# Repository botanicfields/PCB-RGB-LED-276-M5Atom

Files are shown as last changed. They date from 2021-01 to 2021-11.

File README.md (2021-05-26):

# PCB-RGB-LED-276-M5Atom
Circle clock using 276pcs of WS2812C-2020 and an M5Atom

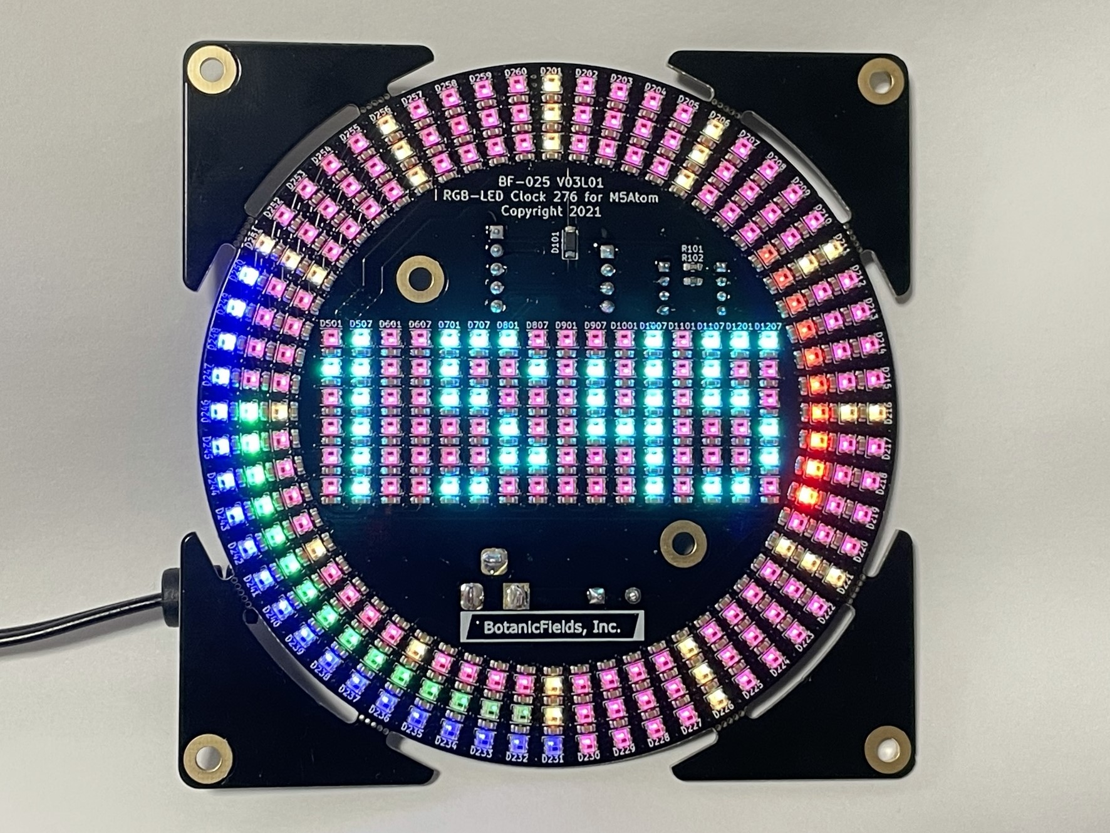
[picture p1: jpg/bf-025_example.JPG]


## 頒布

[M5Atom 用 RGB LED 276 基板](https://www.switch-science.com/catalog/7039/)

[M5Atom 用 RGB LED 276 基板（丸形）](https://botanicfields.booth.pm/items/2940057)

## 説明書

https://github.com/botanicfields/PCB-RGB-LED-276-M5Atom/blob/main/bf-025_doc.pdf

## RTC 基板の増設

　GROVE コネクタ経由でリアルタイムクロック (RTC) 基板を増設できます。スペーサを用いて 2 階建てにできます。

[M5 用 リアルタイムクロック (RTC) 基板](https://www.switch-science.com/catalog/7170/)

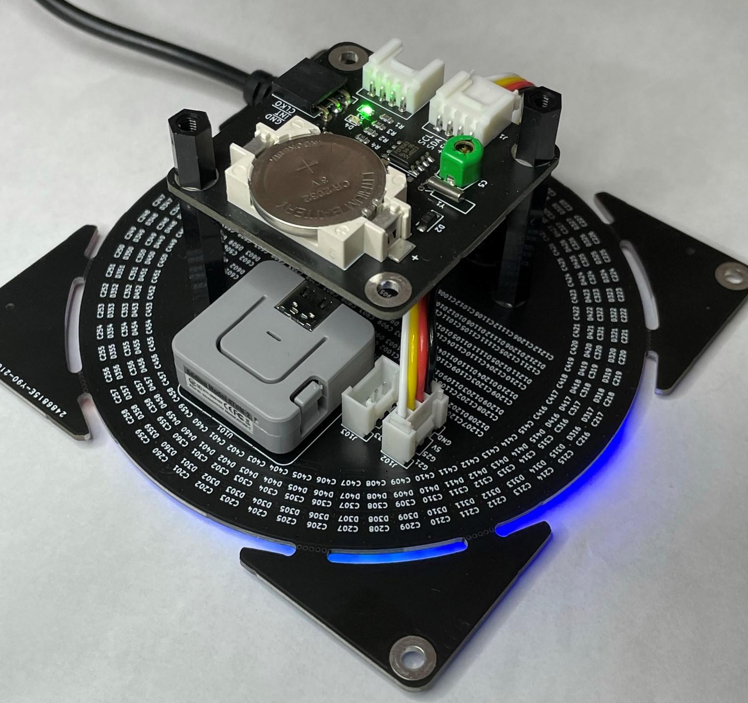
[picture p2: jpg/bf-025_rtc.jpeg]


## 置時計のデモ
　置時計のデモを作成しました。RTC に対応しました。RTC がなくても動作します。以下の機能があります。

- 時・分・秒・曜日・年・月・日の表示（スクロール）
- 時・分・秒のアナログ風表示（彗星の尾）
- 文字盤背景色の変化
- デモ: 時刻表示中のデモ (DemoClock)
- デモ: カウントダウンタイマー (DemoTimeShock)
- デモ: ランプテスト表示 (DemoCyron)
- デモ: 色相環表示 (DemoHueRing)
- デモ: パーリンノイズ (DemoNoise)

　時刻表示中のデモには以下があります。

- 文字色の切替（シアン・赤・緑・青）
- フォント表示（記号・数字、英大文字、英小文字）
- テキスト表示（英大文字、英小文字混在）
- エイリアン

　動作中 M5Atom のボタンで以下を操作します。切替の状況はシリアルモニタで確認できます。

|長押し時間|表示|効果|
|:-:|:-:|:-:|
| -  |Pale|カラーパレットを切替|
|>1 秒|Next|デモを切替、【クロックデモ】デモ内容を切替（文字色、フォント）|
|>2 秒|Exit|デモを切替|
|>3 秒|Temp|色温度を切替|
|>4 秒|Corr|色補正を切替|
|>5 秒|Scal|【パーリンノイズデモ】スケール (x, y) を切替|
|>6 秒|Peri|【パーリンノイズデモ】周期 (z) を切替|
|>7 秒|Null|ボタン操作を取消|

　カウントダウンタイマー動作中、M5Atom のボタンで以下を操作します。

|長押し時間|表示|状態|効果|
|:-:|:-:|:-:|:-:|
| - | - |カウントダウン停止中|カウントダウン開始|
| - | - |カウントダウン中|クイズモードに移行、賞金額を表示|
|>1 秒|Stop| - |カウントダウンを中止、初期値に戻す|
|>2 秒|Time| - |カウントダウンを中止、初期値を変更|
|>3 秒|Pale| - |カラーパレットを変更|
|>4 秒|Exit| - |終了、デモを切替|
|>5 秒|Null| - |ボタン操作を取消|

## 解説 Explanation
"Circle LED Clock by M5Atom and FastLED" in Japanese

[M5Atom と FastLED で 円形 LED 時計を作る](https://qiita.com/BotanicFields/items/a1e182f418d5a07120ac)

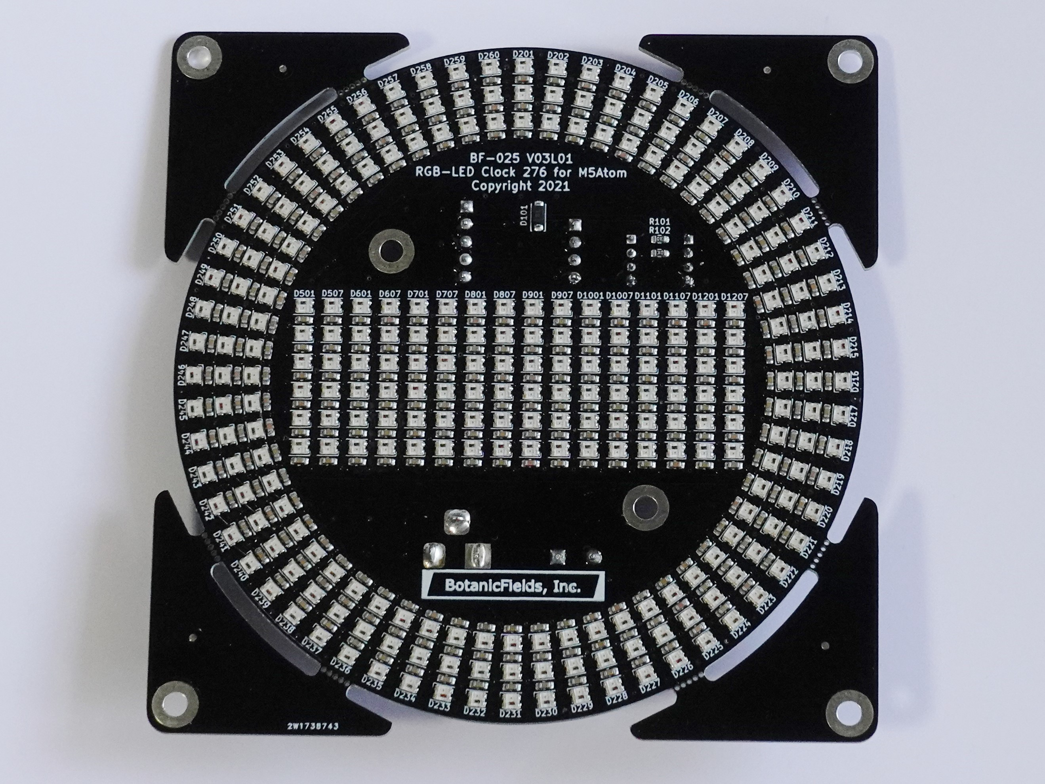
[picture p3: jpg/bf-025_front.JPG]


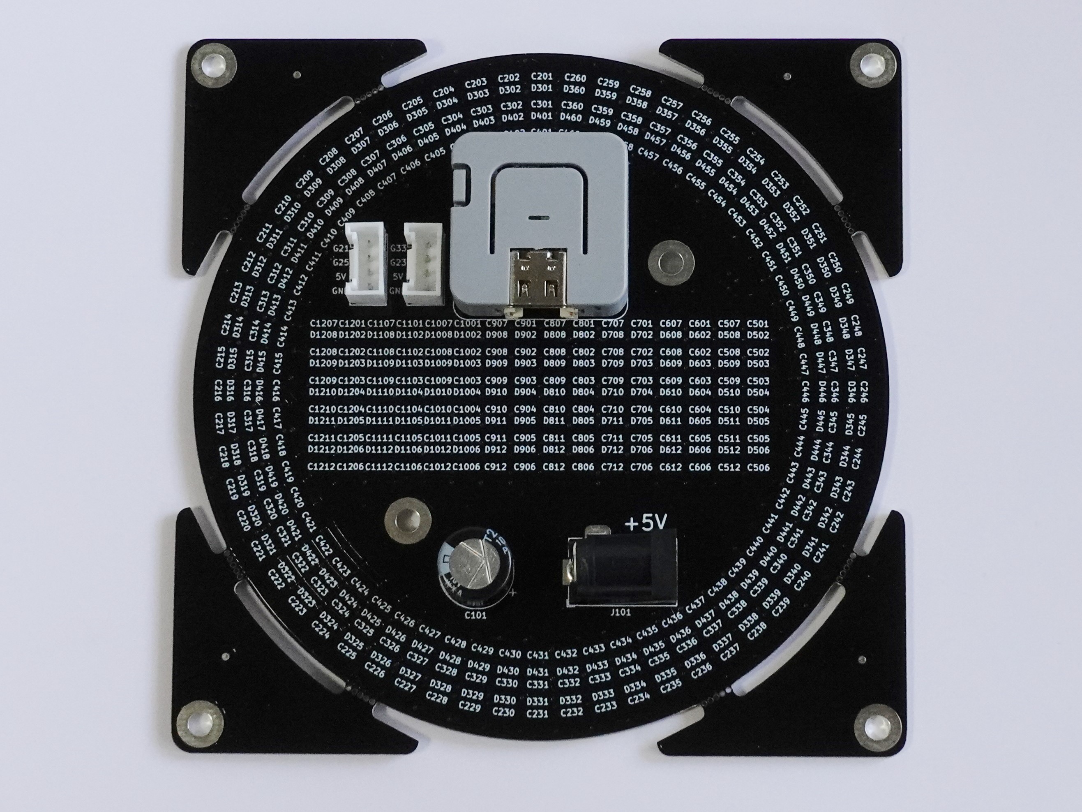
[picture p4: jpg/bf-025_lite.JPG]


## YouTube: Clock Demonstration 

[Clock Demo on BF-025: RGB-LED 276 for M5Atom](https://youtu.be/55dffut1Fk0)

## 3D images by KiCad:

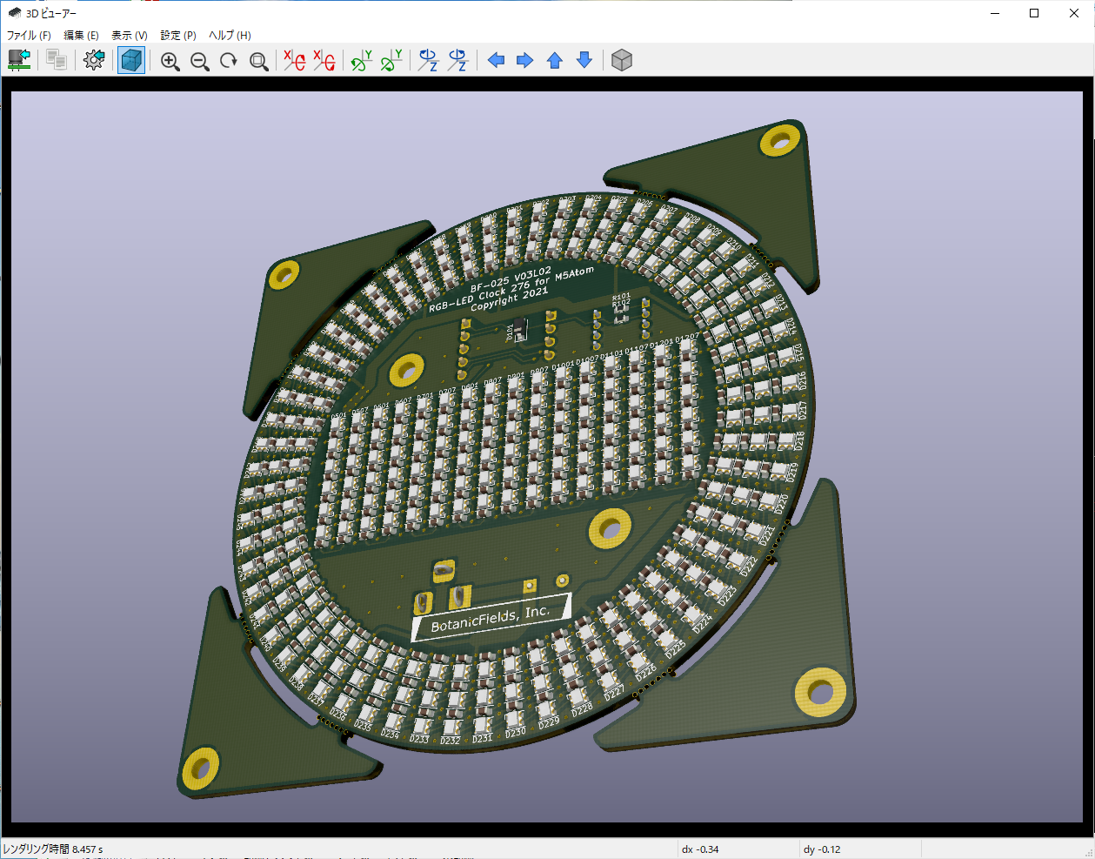
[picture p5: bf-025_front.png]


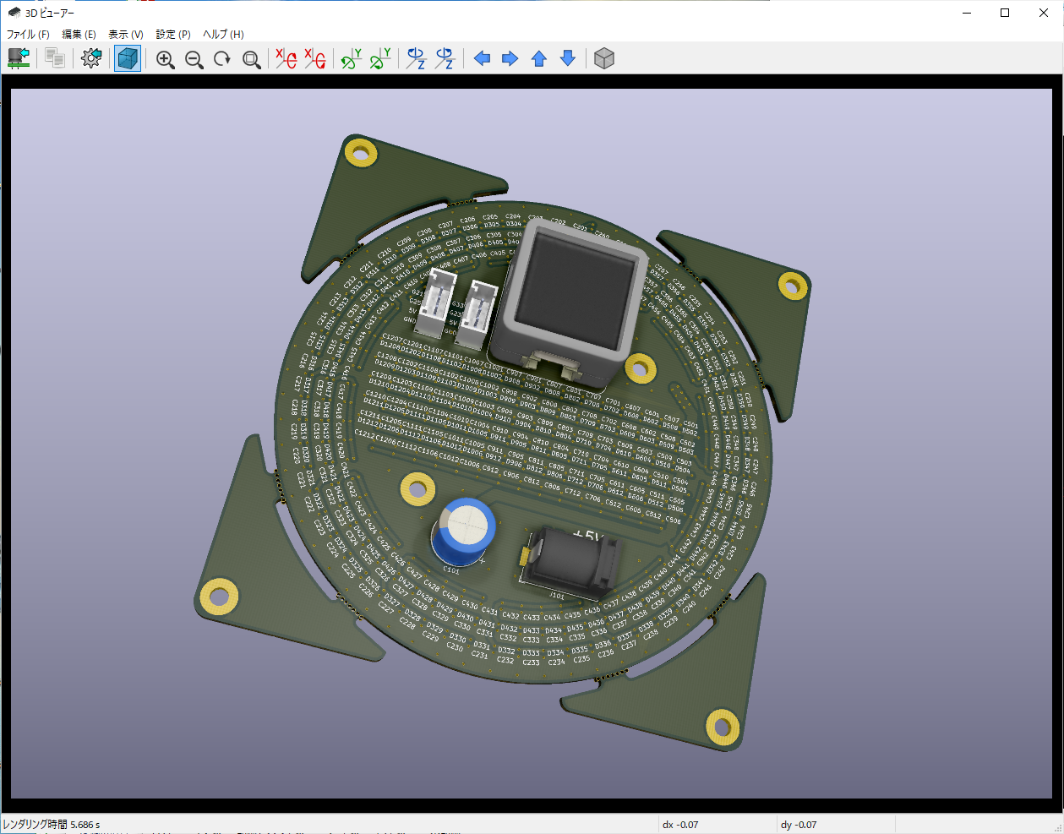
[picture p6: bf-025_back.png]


## YouTube: Examples

[ColorPalette an example from FastLED on BF-025: RGB-LED 276 for M5Atom](https://youtu.be/OUliTGfqcDM)

[DemoReel100 an example from FastLED on BF-025 RGB-LED 276 for M5Atom](https://youtu.be/VHuoHDQSU5E)

[Pacifica an example from FastLED on BF-025 RGB-LED 276 for M5Atom](https://youtu.be/MY5FGuDM8ZY)

[Pride2015 an example from FastLED on BF-025: RGB-LED 276 for M5Atom](https://youtu.be/uj7ePEQMkhk)

[TwinkleFox an exmaple from FastLED on BF025: RGB-LED 276 for M5Atom](https://youtu.be/3NwbCFiiEbc)

## Discussions

[JLCPCB official user group facebook](https://www.facebook.com/groups/JLCPCB/permalink/837468943770299/)

## Practical status of gerber, BOM, pick & place

### V02L01

- JLCPCB: OK

### V03L01

- ALLPCB: OK
- Seeed FusionPCB: OK

### V03L02

- ALLPCB: OK
- JLCPCB: OK

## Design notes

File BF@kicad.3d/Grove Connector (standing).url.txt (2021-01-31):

https://grabcad.com/library/grove-connectors-stand-and-flat-male-plugs-1

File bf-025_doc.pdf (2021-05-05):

BF-025 V03

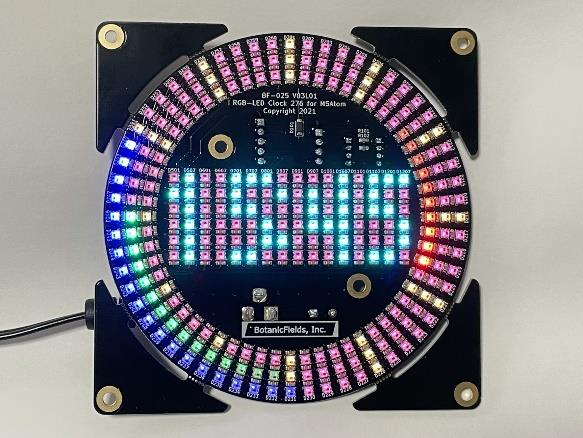
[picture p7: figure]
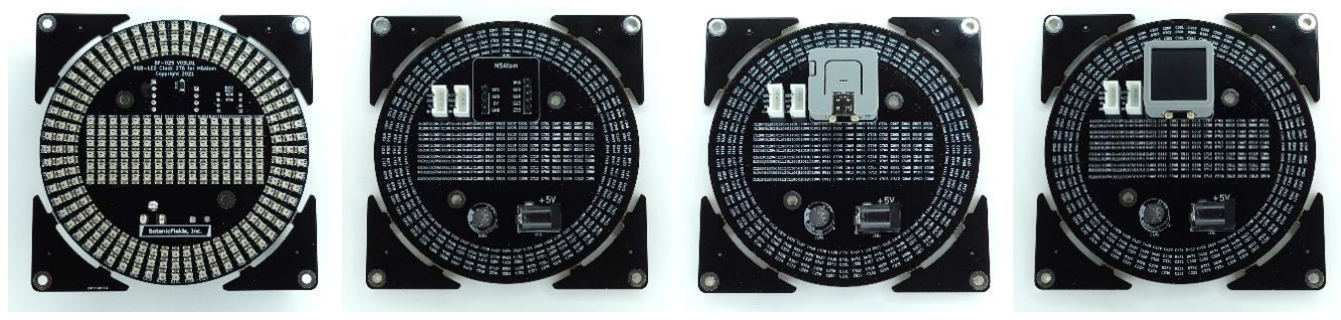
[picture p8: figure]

Copyright 2021 BotanicFields, Inc.

# M5Atom 用 RGB LED 276 基板

小型 RGB LED を、円形 60×3、長方形 16×6、計 276 個並べたプリント基板です。コントローラーに M5Atom Lite または M5Atom Matrix を使用してフルカラー表示 ができます。

※四隅がある基板と、最初から丸形の基板があります。

【安全上のご注意】
LED の明るさは、最大でも 1/4 に抑えてください。 FastLED の場合、明るさを 64 以下としてください。 FastLED.setBrightness(64);
1. 特徴
✓ | アナログ時計表示、デジタル時計表示に適した LED 配置
✓ | M5Atom 用のピンヘッダを装備し、配線の手間を削減
✓ | ポピュラーな NeoPixel 仕様のデジタル RGB LED（スマート LED）を使用
2. 内容物
✓ | プリント基板（完成品）
✓ | 説明書（本書）
※ M5Atom は付属しません。別途ご用意ください。
※ 電源は付属しません。5V 出力の AC アダプター等をご用意ください
| （例）秋月電子通商扱い
| 「スイッチングＡＣアダプター ５Ｖ２Ａ」
| https://akizukidenshi.com/catalog/g/gM-11996/

置時計デモ

表面 | 裏面 | M5Atom Lite 装着 | M5Atom Matrix 装着

3. 製品の特性
本製品は、電子工作や実験用の素材であり RGB LED のプログラミングを楽しんでいただくこと などを目的としています。置時計のデモプログラムには以下の様な制限があります。
✓ | 時刻合わせに Wi-Fi 接続、インターネット接続（NTP）が必須
| （※ Wi-Fi やインターネット接続が不安定だと、置時計自体が不安定になります。）
✓ | RTC やバッテリバックアップを内蔵しておらず、停電時の時刻保持機能がない
✓ | サウンド機能を内蔵しておらず、アラーム機能がない
✓ | 各種センサーを内蔵しておらず、明るさを自動制御する機能などがない
4. 必要なもの
(1) M5Atom
| プリント基板上のピンヘッダに M5Atom Lite または M5Atom Matrix を取り付けます。正し
| い取り付けを目視で確認してから、電源を接続するのが安全です。
| M5Atom Echo は使用できません。
(2) 電源
| DC ジャックから 5V 電源を供給します。M5Atom にも 5V を供給しており USB-C ケーブ
| ルを外しても動作を継続できます。M5Atom からの電源供給はできません。USB-C ケーブルを
| 接続すれば M5Atom 自体は動作します。RGB LED を光らせるためには DC ジャックからの
| 5V 電源の供給が必要です。
| LED の明るさは、最大でも 1/4 に抑えてください。これにより最大でも平均 1A（5W）の消
| 費電流（電力）に抑えることができます。プログラムを誤るなど、予想外の明るさになった場合は、
| 躊躇なく DC ジャックからプラグを抜いてください。
| 置時計のデモプログラムを実行中の消費電流（電力）は平均 0.2A 前後（1W 前後）、パーリン
| ノイズのデモを実行中は平均 0.35A 程度（2W 弱）です。
(3) プログラミング環境
| PC、USB-C ケーブル、ソフトウェアなど、M5Atoｍ にプログラムを書き込む設備環境が必要
| です。デモプログラムは、Arduino IDE を前提としています。コンパイル、書き込み、およびシ
| リアルモニタでの動作状況の確認ができます。Arduino IDE やデモプログラムの入手には一般に
| インターネット接続が必要です。
| Arduino IDE で M5Atom を使用するための準備は、以下の記事が参考になります。
| Qiita「M5Stack シリーズ製品を ArduinoIDE で使う」
| https://qiita.com/akita11/items/f896346d4e8be4673553
| M5Atom のライブラリは、GitHub から最新版を入手して置き換える方が良いと思います。
| さらに、ライブラリマネージャで、以下のライブラリをインストールしてください。
| ➢ FastLED by Daniel Garcia (3.4.0~) https://github.com/FastLED/FastLED
| ➢ WiFIManager by tzapu, tablatronix (2.0.3~) https://github.com/tzapu/WiFiManager

(4) Wi-Fi 接続
置時計のデモプログラムは、M5Atom を Wi-Fi 接続しインターネット上の NTP サーバから 時刻を得ています。
プログラムの書き込み、リセット、または電源オンで実行を開始すると、ランプテスト実行後に Wi-Fi 設定が動作します。Wi-Fi 設定は WiFiManager で行います。詳細は WiFiManager の説 明を参照ください。
https://github.com/tzapu/WiFiManager

大まかな流れ:
① 前回接続した SSID/Key で接続を試みる
② 接続できない場合、M5Atom 自身がアクセスポイントとなって、Wi-Fi クライアント からの接続を待つ
i. スマートフォン等で、アクセスポイントとなった M5Atom に接続する ※ SSID: ChipID に基づく名前、password/key: なし
ii. IP アドレス 192.168.4.1 でブラウザを開く
iii. M5Atom が接続すべき SSID/key を入力する
③ M5Atom が指定された SSID/key で Wi-Fi に接続する

Wi-Fi ルーターとの相性が悪かったり遠かったりすると、前回接続した SSID/Key での接続に 失敗することが多い模様です。この場合、Wi-Fi クライアントからの接続を待ち続けてしまいま す。この様子はシリアルモニタで確認できます。この場合、M5Atom のリセットボタンを押して 再起動すると接続できる場合があります。

(5) GROVE コネクタ
M5Atom の GPIO を GROVE コネクタ 2 個に取り出しています。M5Stack シリーズの仕様 に従い、電源は +5V です。
- | GPIO21※, GPIO25※, +5V, GND | ※3.3V プルアップ（10kΩ）あり
- GPIO33, GPIO23/GPIO34, +5V, GND
(6) パネル・ケースなど
LED 表示のコントラストを上げるには、スモークアクリル板によるパネルが有効です。また、 装飾には埃よけや取り付けのためのケースが必要です。これらの取り付けを想定して 3.2mm のネ ジ穴があります。四隅のネジ穴は、GND には繋がっていません。取り付けの際には、電気的なシ ョート防止および放熱への考慮が必要です。プリント基板の四隅を切り取る場合は、断線や部品破 損を防止するため細心の注意が必要です。
※四隅がある基板と、最初から丸形の基板があります。

5. 情報
回路図、実装図、部品ライブラリ、製造データ、デモプログラム、説明書は、以下にあります。 GitHub 「botanicfields/PCB-RGB-LED-276-M5Atom」 https://github.com/botanicfields/PCB-RGB-LED-276-M5Atom

ハードウェア構成やライブラリ（FastLED）の適用について以下の記事にまとめています。 Qiita 「M5Atom と FastLED で 円形 LED 時計を作る」 https://qiita.com/BotanicFields/items/a1e182f418d5a07120ac

この説明書の内容は古くなっている可能性があります。最新情報は、上記を参照ください。

6. 置時計
置時計のデモプログラムを作成しました。動作の様子が YouTube にあります。 YouTube 「Clock Demo on BF-025: RGB-LED 276 for M5Atom」 https://youtu.be/55dffut1Fk0

Arduino IDE において、名前 BF-025 のフォルダをまるごと置いてください。 GitHub 「PCB-RGB-LED-276-M5Atom/BF-025/」 https://github.com/botanicfields/PCB-RGB-LED-276-M5Atom/tree/main/BF-025

置時計デモプログラムには以下の機能があります。
✓ | 時・分・秒・曜日・年・月・日をスクロール表示
✓ | 時・分・秒をアナログ風に表示（彗星の尾）
✓ | 文字盤背景色が変化
✓ | デモ: 時刻表示中のデモ (DemoClock)
✓ | デモ: カウントダウンタイマー (DemoTimeShock)
✓ | デモ: ランプテスト表示 (DemoCyron)
✓ | デモ: 色相環表示 (DemoHueRing)
✓ | デモ: パーリンノイズ (DemoNoise)

時刻表示中のデモには以下があります。
✓ | 文字色を切替（シアン・赤・緑・青）
✓ | フォント一覧を表示（記号・数字、英大文字、英小文字）
✓ | テキスト（サンプル）を表示（英大文字、英小文字混在）
✓ | エイリアンを表示

動作中 M5Atom のボタンで、色やデモを切り替えることができます。ボタン操作には長押しを利 用しています。切替の状況はシリアルモニタで確認できます。

長押し時間 | 表示 | 効果
- | Pale | カラーパレットを切替
>1 秒 | Next | デモを切替、【クロックデモ】デモ内容を切替（文字色、フォント）
>2 秒 | Exit | デモを切替
>3 秒 | Temp | 色温度を切替
>4 秒 | Corr | 色補正を切替
>5 秒 | Scal | 【パーリンノイズデモ】スケール (x, y) を切替
>6 秒 | Peri | 【パーリンノイズデモ】周期 (z) を切替
>7 秒 | Null | ボタン操作を取消

カウントダウンタイマーのデモ動作中、M5Atom のボタン操作は以下のとおりです。
長押し時間 | 表示 | 状態 | 効果
- | - | カウントダウン停止中 | カウントダウン開始
- | - | カウントダウン中 | クイズモードに移行、賞金額（千円）を表示
>1 秒 | Stop | - | カウントダウンを中止、初期値に戻す
>2 秒 | Time | - | カウントダウンを中止、初期値を変更
>3 秒 | Pale | - | カラーパレットを変更
>4 秒 | Exit | - | 終了、デモを切替
>5 秒 | Null | - | ボタン操作を取消
7. 修理について
頒布にあたり正常動作を確認しておりますが、使用中に不具合が発生する可能性はゼロではあり ません。万一不具合が発生した場合は、ご自身で修理なさるか、または提供元にご相談ください。
8. 提供元
ボタニック BotanicFields, Inc.
https://www.facebook.com/botanicfieldshttps://twitter.com/botanicfields
以上

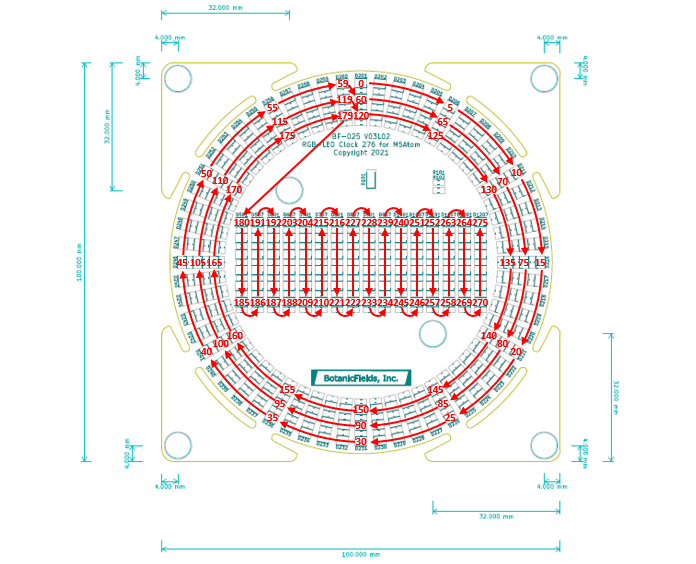
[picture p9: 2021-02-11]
bf-025_led_connection.png

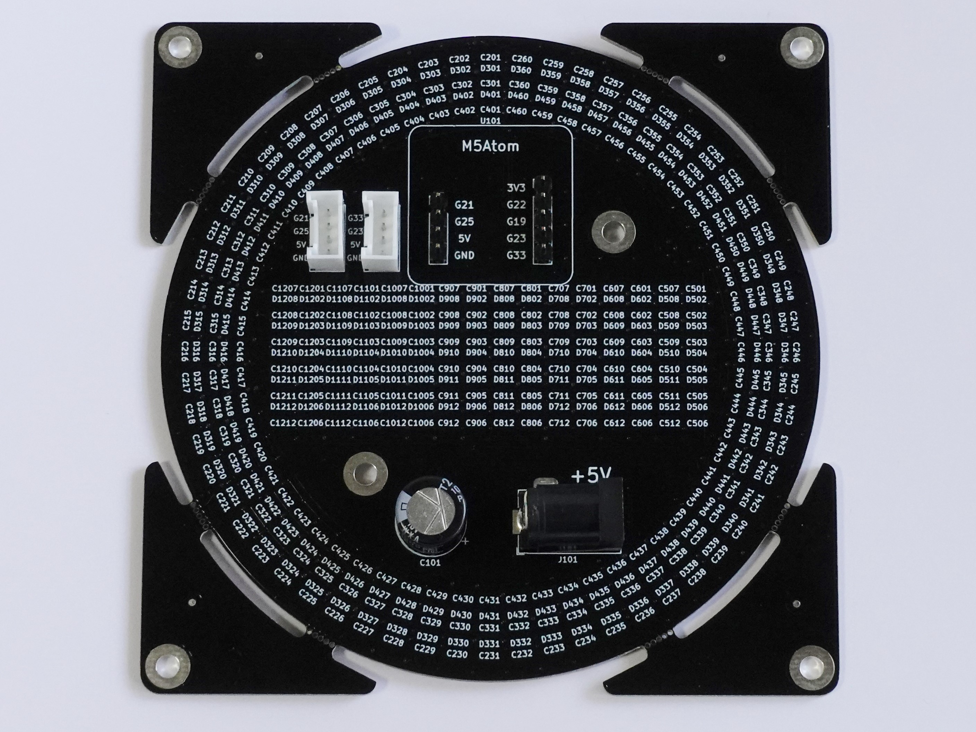
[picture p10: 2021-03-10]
jpg/bf-025_back.JPG

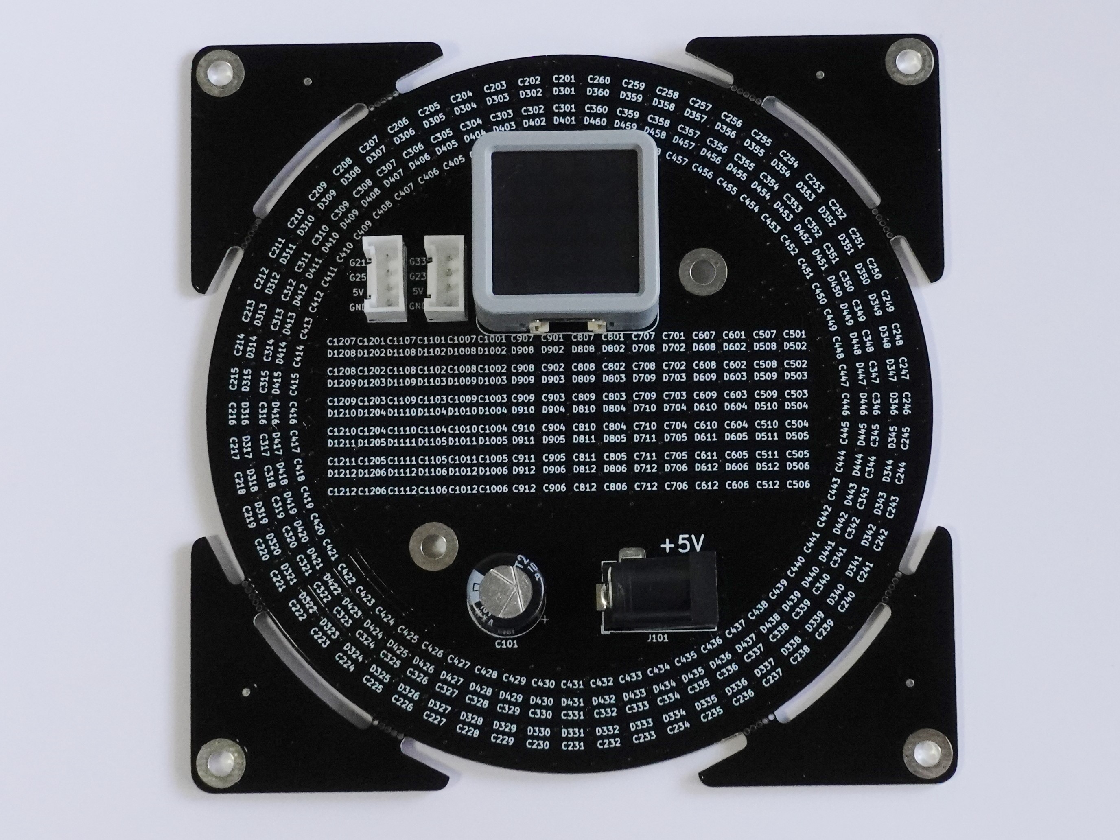
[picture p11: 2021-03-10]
jpg/bf-025_matrix.JPG

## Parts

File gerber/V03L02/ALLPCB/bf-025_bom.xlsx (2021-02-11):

Qty | MPN | Supplier | Reference | Value | Package | Type | Notes | Link
276 | CC0603KRX7R9BB104 | LCSC | C201,C202,C203,C204,C205,C206,C207,C208,C209,C210,C211,C212,C213,C214,C215,C216,C217,C218,C219,C220,C221,C222,C223,C224,C225,C226,C227,C228,C229,C230,C231,C232,C233,C234,C235,C236,C237,C238,C239,C240,C241,C242,C243,C244,C245,C246,C247,C248,C249,C250,C251,C252,C253,C254,C255,C256,C257,C258,C259,C260,C301,C302,C303,C304,C305,C306,C307,C308,C309,C310,C311,C312,C313,C314,C315,C316,C317,C318,C319,C320,C321,C322,C323,C324,C325,C326,C327,C328,C329,C330,C331,C332,C333,C334,C335,C336,C337,C338,C339,C340,C341,C342,C343,C344,C345,C346,C347,C348,C349,C350,C351,C352,C353,C354,C355,C356,C357,C358,C359,C360,C401,C402,C403,C404,C405,C406,C407,C408,C409,C410,C411,C412,C413,C414,C415,C416,C417,C418,C419,C420,C421,C422,C423,C424,C425,C426,C427,C428,C429,C430,C431,C432,C433,C434,C435,C436,C437,C438,C439,C440,C441,C442,C443,C444,C445,C446,C447,C448,C449,C450,C451,C452,C453,C454,C455,C456,C457,C458,C459,C460,C501,C502,C503,C504,C505,C506,C507,C508,C509,C510,C511,C512,C601,C602,C603,C604,C605,C606,C607,C608,C609,C610,C611,C612,C701,C702,C703,C704,C705,C706,C707,C708,C709,C710,C711,C712,C801,C802,C803,C804,C805,C806,C807,C808,C809,C810,C811,C812,C901,C902,C903,C904,C905,C906,C907,C908,C909,C910,C911,C912,C1001,C1002,C1003,C1004,C1005,C1006,C1007,C1008,C1009,C1010,C1011,C1012,C1101,C1102,C1103,C1104,C1105,C1106,C1107,C1108,C1109,C1110,C1111,C1112,C1201,C1202,C1203,C1204,C1205,C1206,C1207,C1208,C1209,C1210,C1211,C1212 | 100n | C0603 | SMD | LCSC: C14663 Substitutable
1 | B5819W | LCSC | D101 | B5819W | SOD-123 | SMD | LCSC: C8598
276 | WS2812C-2020 | LCSC | D201,D202,D203,D204,D205,D206,D207,D208,D209,D210,D211,D212,D213,D214,D215,D216,D217,D218,D219,D220,D221,D222,D223,D224,D225,D226,D227,D228,D229,D230,D231,D232,D233,D234,D235,D236,D237,D238,D239,D240,D241,D242,D243,D244,D245,D246,D247,D248,D249,D250,D251,D252,D253,D254,D255,D256,D257,D258,D259,D260,D301,D302,D303,D304,D305,D306,D307,D308,D309,D310,D311,D312,D313,D314,D315,D316,D317,D318,D319,D320,D321,D322,D323,D324,D325,D326,D327,D328,D329,D330,D331,D332,D333,D334,D335,D336,D337,D338,D339,D340,D341,D342,D343,D344,D345,D346,D347,D348,D349,D350,D351,D352,D353,D354,D355,D356,D357,D358,D359,D360,D401,D402,D403,D404,D405,D406,D407,D408,D409,D410,D411,D412,D413,D414,D415,D416,D417,D418,D419,D420,D421,D422,D423,D424,D425,D426,D427,D428,D429,D430,D431,D432,D433,D434,D435,D436,D437,D438,D439,D440,D441,D442,D443,D444,D445,D446,D447,D448,D449,D450,D451,D452,D453,D454,D455,D456,D457,D458,D459,D460,D501,D502,D503,D504,D505,D506,D507,D508,D509,D510,D511,D512,D601,D602,D603,D604,D605,D606,D607,D608,D609,D610,D611,D612,D701,D702,D703,D704,D705,D706,D707,D708,D709,D710,D711,D712,D801,D802,D803,D804,D805,D806,D807,D808,D809,D810,D811,D812,D901,D902,D903,D904,D905,D906,D907,D908,D909,D910,D911,D912,D1001,D1002,D1003,D1004,D1005,D1006,D1007,D1008,D1009,D1010,D1011,D1012,D1101,D1102,D1103,D1104,D1105,D1106,D1107,D1108,D1109,D1110,D1111,D1112,D1201,D1202,D1203,D1204,D1205,D1206,D1207,D1208,D1209,D1210,D1211,D1212 | WS2812C-2020 | D2020 | SMD | LCSC: C965556 | http://www.world-semi.com/Certifications/details-139-4.html
2 | 0603WAF1002T5E | LCSC | R101,R102 | 10kOhm | R0603 | SMD | LCSC: C25804 Substitutable

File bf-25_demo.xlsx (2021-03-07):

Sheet: Font Editor
 | Font Editor 6*6
 |  |  |  |  | ↓フォントを編集します |  |  |  |  |  |  |  |  | フィルターで空白行を非表示にし、コピーしてください↓
 | code | hex | character |  | Editing area |  |  |  |  |  |  |  |  | x*y = 6*6 fonts data
1 |  |  |  |  | 0 | 1 | 2 | 3 | 4 | 5 | 6 | 7
2 |  |  |  |  | 128 | 64 | 32 | 16 | 8 | 4 | 2 | 1
3 | 0 | 0x00 | 0 |  |  |  |  |  |  |  |  |  |  | { 0x60, 0xA0, 0xA0, 0xA0, 0xA0, 0xC0, }, // 0x00 0
4 |  |  |  | 1 |  | 1 | 1 |  |  |  |  |  | 0x60,
5 |  |  |  | 2 | 1 |  | 1 |  |  |  |  |  | 0xA0,
6 |  |  |  | 3 | 1 |  | 1 |  |  |  |  |  | 0xA0,
7 |  |  |  | 4 | 1 |  | 1 |  |  |  |  |  | 0xA0,
8 |  |  |  | 5 | 1 |  | 1 |  |  |  |  |  | 0xA0,
9 |  |  |  | 6 | 1 | 1 |  |  |  |  |  |  | 0xC0,
10 | 1 | 0x01 | 1 |  |  |  |  |  |  |  |  |  |  | { 0x40, 0xC0, 0x40, 0x40, 0x40, 0x40, }, // 0x01 1
11 |  |  |  | 1 |  | 1 |  |  |  |  |  |  | 0x40,
12 |  |  |  | 2 | 1 | 1 |  |  |  |  |  |  | 0xC0,
13 |  |  |  | 3 |  | 1 |  |  |  |  |  |  | 0x40,
14 |  |  |  | 4 |  | 1 |  |  |  |  |  |  | 0x40,
15 |  |  |  | 5 |  | 1 |  |  |  |  |  |  | 0x40,
16 |  |  |  | 6 |  | 1 |  |  |  |  |  |  | 0x40,
17 | 2 | 0x02 | 2 |  |  |  |  |  |  |  |  |  |  | { 0xC0, 0x20, 0x20, 0x40, 0x80, 0xE0, }, // 0x02 2
18 |  |  |  | 1 | 1 | 1 |  |  |  |  |  |  | 0xC0,
19 |  |  |  | 2 |  |  | 1 |  |  |  |  |  | 0x20,
20 |  |  |  | 3 |  |  | 1 |  |  |  |  |  | 0x20,
21 |  |  |  | 4 |  | 1 |  |  |  |  |  |  | 0x40,
22 |  |  |  | 5 | 1 |  |  |  |  |  |  |  | 0x80,
23 |  |  |  | 6 | 1 | 1 | 1 |  |  |  |  |  | 0xE0,
24 | 3 | 0x03 | 3 |  |  |  |  |  |  |  |  |  |  | { 0xC0, 0x20, 0x40, 0x20, 0x20, 0xC0, }, // 0x03 3
25 |  |  |  | 1 | 1 | 1 |  |  |  |  |  |  | 0xC0,
26 |  |  |  | 2 |  |  | 1 |  |  |  |  |  | 0x20,
27 |  |  |  | 3 |  | 1 |  |  |  |  |  |  | 0x40,
28 |  |  |  | 4 |  |  | 1 |  |  |  |  |  | 0x20,
29 |  |  |  | 5 |  |  | 1 |  |  |  |  |  | 0x20,
30 |  |  |  | 6 | 1 | 1 |  |  |  |  |  |  | 0xC0,
31 | 4 | 0x04 | 4 |  |  |  |  |  |  |  |  |  |  | { 0x20, 0xA0, 0xA0, 0xE0, 0x20, 0x20, }, // 0x04 4
32 |  |  |  | 1 |  |  | 1 |  |  |  |  |  | 0x20,
33 |  |  |  | 2 | 1 |  | 1 |  |  |  |  |  | 0xA0,
34 |  |  |  | 3 | 1 |  | 1 |  |  |  |  |  | 0xA0,
35 |  |  |  | 4 | 1 | 1 | 1 |  |  |  |  |  | 0xE0,
36 |  |  |  | 5 |  |  | 1 |  |  |  |  |  | 0x20,
37 |  |  |  | 6 |  |  | 1 |  |  |  |  |  | 0x20,
38 | 5 | 0x05 | 5 |  |  |  |  |  |  |  |  |  |  | { 0xE0, 0x80, 0xC0, 0x20, 0x20, 0xC0, }, // 0x05 5
39 |  |  |  | 1 | 1 | 1 | 1 |  |  |  |  |  | 0xE0,
40 |  |  |  | 2 | 1 |  |  |  |  |  |  |  | 0x80,
41 |  |  |  | 3 | 1 | 1 |  |  |  |  |  |  | 0xC0,
42 |  |  |  | 4 |  |  | 1 |  |  |  |  |  | 0x20,
43 |  |  |  | 5 |  |  | 1 |  |  |  |  |  | 0x20,
44 |  |  |  | 6 | 1 | 1 |  |  |  |  |  |  | 0xC0,
45 | 6 | 0x06 | 6 |  |  |  |  |  |  |  |  |  |  | { 0x60, 0x80, 0xC0, 0xA0, 0xA0, 0x40, }, // 0x06 6
46 |  |  |  | 1 |  | 1 | 1 |  |  |  |  |  | 0x60,
47 |  |  |  | 2 | 1 |  |  |  |  |  |  |  | 0x80,
48 |  |  |  | 3 | 1 | 1 |  |  |  |  |  |  | 0xC0,
49 |  |  |  | 4 | 1 |  | 1 |  |  |  |  |  | 0xA0,
50 |  |  |  | 5 | 1 |  | 1 |  |  |  |  |  | 0xA0,
51 |  |  |  | 6 |  | 1 |  |  |  |  |  |  | 0x40,
52 | 7 | 0x07 | 7 |  |  |  |  |  |  |  |  |  |  | { 0xE0, 0x20, 0x20, 0x40, 0x80, 0x80, }, // 0x07 7
53 |  |  |  | 1 | 1 | 1 | 1 |  |  |  |  |  | 0xE0,
54 |  |  |  | 2 |  |  | 1 |  |  |  |  |  | 0x20,
55 |  |  |  | 3 |  |  | 1 |  |  |  |  |  | 0x20,
56 |  |  |  | 4 |  | 1 |  |  |  |  |  |  | 0x40,
57 |  |  |  | 5 | 1 |  |  |  |  |  |  |  | 0x80,
58 |  |  |  | 6 | 1 |  |  |  |  |  |  |  | 0x80,
59 | 8 | 0x08 | 8 |  |  |  |  |  |  |  |  |  |  | { 0x60, 0xA0, 0x40, 0xA0, 0xA0, 0xC0, }, // 0x08 8
60 |  |  |  | 1 |  | 1 | 1 |  |  |  |  |  | 0x60,
61 |  |  |  | 2 | 1 |  | 1 |  |  |  |  |  | 0xA0,
62 |  |  |  | 3 |  | 1 |  |  |  |  |  |  | 0x40,
63 |  |  |  | 4 | 1 |  | 1 |  |  |  |  |  | 0xA0,
64 |  |  |  | 5 | 1 |  | 1 |  |  |  |  |  | 0xA0,
65 |  |  |  | 6 | 1 | 1 |  |  |  |  |  |  | 0xC0,
66 | 9 | 0x09 | 9 |  |  |  |  |  |  |  |  |  |  | { 0x40, 0xA0, 0xA0, 0x60, 0x20, 0xC0, }, // 0x09 9
67 |  |  |  | 1 |  | 1 |  |  |  |  |  |  | 0x40,
68 |  |  |  | 2 | 1 |  | 1 |  |  |  |  |  | 0xA0,
69 |  |  |  | 3 | 1 |  | 1 |  |  |  |  |  | 0xA0,
70 |  |  |  | 4 |  | 1 | 1 |  |  |  |  |  | 0x60,
71 |  |  |  | 5 |  |  | 1 |  |  |  |  |  | 0x20,
72 |  |  |  | 6 | 1 | 1 |  |  |  |  |  |  | 0xC0,
73 | 10 | 0x0A | A |  |  |  |  |  |  |  |  |  |  | { 0x40, 0xA0, 0xA0, 0xE0, 0xA0, 0xA0, }, // 0x0A A
74 |  |  |  | 1 |  | 1 |  |  |  |  |  |  | 0x40,
75 |  |  |  | 2 | 1 |  | 1 |  |  |  |  |  | 0xA0,
76 |  |  |  | 3 | 1 |  | 1 |  |  |  |  |  | 0xA0,
77 |  |  |  | 4 | 1 | 1 | 1 |  |  |  |  |  | 0xE0,
78 |  |  |  | 5 | 1 |  | 1 |  |  |  |  |  | 0xA0,
79 |  |  |  | 6 | 1 |  | 1 |  |  |  |  |  | 0xA0,
80 | 11 | 0x0B | B |  |  |  |  |  |  |  |  |  |  | { 0xC0, 0xA0, 0xC0, 0xA0, 0xA0, 0xC0, }, // 0x0B B
81 |  |  |  | 1 | 1 | 1 |  |  |  |  |  |  | 0xC0,
82 |  |  |  | 2 | 1 |  | 1 |  |  |  |  |  | 0xA0,
83 |  |  |  | 3 | 1 | 1 |  |  |  |  |  |  | 0xC0,
84 |  |  |  | 4 | 1 |  | 1 |  |  |  |  |  | 0xA0,
85 |  |  |  | 5 | 1 |  | 1 |  |  |  |  |  | 0xA0,
86 |  |  |  | 6 | 1 | 1 |  |  |  |  |  |  | 0xC0,
87 | 12 | 0x0C | C |  |  |  |  |  |  |  |  |  |  | { 0x60, 0x80, 0x80, 0x80, 0x80, 0x60, }, // 0x0C C
88 |  |  |  | 1 |  | 1 | 1 |  |  |  |  |  | 0x60,
89 |  |  |  | 2 | 1 |  |  |  |  |  |  |  | 0x80,
90 |  |  |  | 3 | 1 |  |  |  |  |  |  |  | 0x80,
91 |  |  |  | 4 | 1 |  |  |  |  |  |  |  | 0x80,
92 |  |  |  | 5 | 1 |  |  |  |  |  |  |  | 0x80,
93 |  |  |  | 6 |  | 1 | 1 |  |  |  |  |  | 0x60,
94 | 13 | 0x0D | D |  |  |  |  |  |  |  |  |  |  | { 0xC0, 0xA0, 0xA0, 0xA0, 0xA0, 0xC0, }, // 0x0D D
95 |  |  |  | 1 | 1 | 1 |  |  |  |  |  |  | 0xC0,
96 |  |  |  | 2 | 1 |  | 1 |  |  |  |  |  | 0xA0,
97 |  |  |  | 3 | 1 |  | 1 |  |  |  |  |  | 0xA0,
98 |  |  |  | 4 | 1 |  | 1 |  |  |  |  |  | 0xA0,
99 |  |  |  | 5 | 1 |  | 1 |  |  |  |  |  | 0xA0,
100 |  |  |  | 6 | 1 | 1 |  |  |  |  |  |  | 0xC0,
101 | 14 | 0x0E | E |  |  |  |  |  |  |  |  |  |  | { 0xE0, 0x80, 0xE0, 0x80, 0x80, 0xE0, }, // 0x0E E
102 |  |  |  | 1 | 1 | 1 | 1 |  |  |  |  |  | 0xE0,
103 |  |  |  | 2 | 1 |  |  |  |  |  |  |  | 0x80,
104 |  |  |  | 3 | 1 | 1 | 1 |  |  |  |  |  | 0xE0,
105 |  |  |  | 4 | 1 |  |  |  |  |  |  |  | 0x80,
106 |  |  |  | 5 | 1 |  |  |  |  |  |  |  | 0x80,
107 |  |  |  | 6 | 1 | 1 | 1 |  |  |  |  |  | 0xE0,
108 | 15 | 0x0F | F |  |  |  |  |  |  |  |  |  |  | { 0xE0, 0x80, 0xE0, 0x80, 0x80, 0x80, }, // 0x0F F
109 |  |  |  | 1 | 1 | 1 | 1 |  |  |  |  |  | 0xE0,
110 |  |  |  | 2 | 1 |  |  |  |  |  |  |  | 0x80,
111 |  |  |  | 3 | 1 | 1 | 1 |  |  |  |  |  | 0xE0,
112 |  |  |  | 4 | 1 |  |  |  |  |  |  |  | 0x80,
113 |  |  |  | 5 | 1 |  |  |  |  |  |  |  | 0x80,
114 |  |  |  | 6 | 1 |  |  |  |  |  |  |  | 0x80,
115 | 16 | 0x10 | Crab1L |  |  |  |  |  |  |  |  |  |  | { 0x60, 0x3C, 0x6C, 0xFC, 0x90, 0x18, }, // 0x10 Crab1L
116 |  |  |  | 1 |  | 1 | 1 |  |  |  |  |  | 0x60,
117 |  |  |  | 2 |  |  | 1 | 1 | 1 | 1 |  |  | 0x3C,
118 |  |  |  | 3 |  | 1 | 1 |  | 1 | 1 |  |  | 0x6C,
119 |  |  |  | 4 | 1 | 1 | 1 | 1 | 1 | 1 |  |  | 0xFC,
120 |  |  |  | 5 | 1 |  |  | 1 |  |  |  |  | 0x90,
121 |  |  |  | 6 |  |  |  | 1 | 1 |  |  |  | 0x18,
122 | 17 | 0x11 | Crab1R |  |  |  |  |  |  |  |  |  |  | { 0x30, 0xE0, 0xB0, 0xF8, 0x48, 0xC0, }, // 0x11 Crab1R
123 |  |  |  | 1 |  |  | 1 | 1 |  |  |  |  | 0x30,
124 |  |  |  | 2 | 1 | 1 | 1 |  |  |  |  |  | 0xE0,
125 |  |  |  | 3 | 1 |  | 1 | 1 |  |  |  |  | 0xB0,
126 |  |  |  | 4 | 1 | 1 | 1 | 1 | 1 |  |  |  | 0xF8,
127 |  |  |  | 5 |  | 1 |  |  | 1 |  |  |  | 0x48,
128 |  |  |  | 6 | 1 | 1 |  |  |  |  |  |  | 0xC0,
129 | 18 | 0x12 | Crab2L |  |  |  |  |  |  |  |  |  |  | { 0x20, 0xBC, 0xEC, 0x7C, 0x10, 0x30, }, // 0x12 Crab2L
130 |  |  |  | 1 |  |  | 1 |  |  |  |  |  | 0x20,
131 |  |  |  | 2 | 1 |  | 1 | 1 | 1 | 1 |  |  | 0xBC,
132 |  |  |  | 3 | 1 | 1 | 1 |  | 1 | 1 |  |  | 0xEC,
133 |  |  |  | 4 |  | 1 | 1 | 1 | 1 | 1 |  |  | 0x7C,
134 |  |  |  | 5 |  |  |  | 1 |  |  |  |  | 0x10,
135 |  |  |  | 6 |  |  | 1 | 1 |  |  |  |  | 0x30,
136 | 19 | 0x13 | Crab2R |  |  |  |  |  |  |  |  |  |  | { 0x20, 0xE8, 0xB8, 0xF0, 0x40, 0x60, }, // 0x13 Crab2R
137 |  |  |  | 1 |  |  | 1 |  |  |  |  |  | 0x20,
138 |  |  |  | 2 | 1 | 1 | 1 |  | 1 |  |  |  | 0xE8,
139 |  |  |  | 3 | 1 |  | 1 | 1 | 1 |  |  |  | 0xB8,
140 |  |  |  | 4 | 1 | 1 | 1 | 1 |  |  |  |  | 0xF0,
141 |  |  |  | 5 |  | 1 |  |  |  |  |  |  | 0x40,
142 |  |  |  | 6 |  | 1 | 1 |  |  |  |  |  | 0x60,
143 | 20 | 0x14 | Octopus1L |  |  |  |  |  |  |  |  |  |  | { 0x3C, 0x7C, 0x6C, 0x7C, 0x24, 0xC8, }, // 0x14 Octopus1L
144 |  |  |  | 1 |  |  | 1 | 1 | 1 | 1 |  |  | 0x3C,
145 |  |  |  | 2 |  | 1 | 1 | 1 | 1 | 1 |  |  | 0x7C,
146 |  |  |  | 3 |  | 1 | 1 |  | 1 | 1 |  |  | 0x6C,
147 |  |  |  | 4 |  | 1 | 1 | 1 | 1 | 1 |  |  | 0x7C,
148 |  |  |  | 5 |  |  | 1 |  |  | 1 |  |  | 0x24,
149 |  |  |  | 6 | 1 | 1 |  |  | 1 |  |  |  | 0xC8,
150 | 21 | 0x15 | Octopus1R |  |  |  |  |  |  |  |  |  |  | { 0xE0, 0xF0, 0xB0, 0xF0, 0x20, 0x98, }, // 0x15 Octopus1R
151 |  |  |  | 1 | 1 | 1 | 1 |  |  |  |  |  | 0xE0,
152 |  |  |  | 2 | 1 | 1 | 1 | 1 |  |  |  |  | 0xF0,
153 |  |  |  | 3 | 1 |  | 1 | 1 |  |  |  |  | 0xB0,
154 |  |  |  | 4 | 1 | 1 | 1 | 1 |  |  |  |  | 0xF0,
155 |  |  |  | 5 |  |  | 1 |  |  |  |  |  | 0x20,
156 |  |  |  | 6 | 1 |  |  | 1 | 1 |  |  |  | 0x98,
157 | 22 | 0x16 | Octopus2L |  |  |  |  |  |  |  |  |  |  | { 0x3C, 0x7C, 0x6C, 0x7C, 0x24, 0x14, }, // 0x16 Octopus2L
158 |  |  |  | 1 |  |  | 1 | 1 | 1 | 1 |  |  | 0x3C,
159 |  |  |  | 2 |  | 1 | 1 | 1 | 1 | 1 |  |  | 0x7C,
160 |  |  |  | 3 |  | 1 | 1 |  | 1 | 1 |  |  | 0x6C,
161 |  |  |  | 4 |  | 1 | 1 | 1 | 1 | 1 |  |  | 0x7C,
162 |  |  |  | 5 |  |  | 1 |  |  | 1 |  |  | 0x24,
163 |  |  |  | 6 |  |  |  | 1 |  | 1 |  |  | 0x14,
164 | 23 | 0x17 | Octopus2R |  |  |  |  |  |  |  |  |  |  | { 0xE0, 0xF0, 0xB0, 0xF0, 0x20, 0x40, }, // 0x17 Octopus2R
165 |  |  |  | 1 | 1 | 1 | 1 |  |  |  |  |  | 0xE0,
166 |  |  |  | 2 | 1 | 1 | 1 | 1 |  |  |  |  | 0xF0,
167 |  |  |  | 3 | 1 |  | 1 | 1 |  |  |  |  | 0xB0,
168 |  |  |  | 4 | 1 | 1 | 1 | 1 |  |  |  |  | 0xF0,
169 |  |  |  | 5 |  |  | 1 |  |  |  |  |  | 0x20,
170 |  |  |  | 6 |  | 1 |  |  |  |  |  |  | 0x40,
171 | 24 | 0x18 | Squid1L |  |  |  |  |  |  |  |  |  |  | { 0x04, 0x1C, 0x74, 0xFC, 0x24, 0x10, }, // 0x18 Squid1L
172 |  |  |  | 1 |  |  |  |  |  | 1 |  |  | 0x04,
173 |  |  |  | 2 |  |  |  | 1 | 1 | 1 |  |  | 0x1C,
174 |  |  |  | 3 |  | 1 | 1 | 1 |  | 1 |  |  | 0x74,
175 |  |  |  | 4 | 1 | 1 | 1 | 1 | 1 | 1 |  |  | 0xFC,
176 |  |  |  | 5 |  |  | 1 |  |  | 1 |  |  | 0x24,
177 |  |  |  | 6 |  |  |  | 1 |  |  |  |  | 0x10,
178 | 25 | 0x19 | Squid1R |  |  |  |  |  |  |  |  |  |  | { 0x00, 0xC0, 0x70, 0xF8, 0x20, 0x40, }, // 0x19 Squid1R
179 |  |  |  | 1 |  |  |  |  |  |  |  |  | 0x00,
180 |  |  |  | 2 | 1 | 1 |  |  |  |  |  |  | 0xC0,
181 |  |  |  | 3 |  | 1 | 1 | 1 |  |  |  |  | 0x70,
182 |  |  |  | 4 | 1 | 1 | 1 | 1 | 1 |  |  |  | 0xF8,
183 |  |  |  | 5 |  |  | 1 |  |  |  |  |  | 0x20,
184 |  |  |  | 6 |  | 1 |  |  |  |  |  |  | 0x40,
185 | 26 | 0x1A | Squid2L |  |  |  |  |  |  |  |  |  |  | { 0x04, 0x1C, 0x74, 0xFC, 0x24, 0xC0, }, // 0x1A Squid2L
186 |  |  |  | 1 |  |  |  |  |  | 1 |  |  | 0x04,
187 |  |  |  | 2 |  |  |  | 1 | 1 | 1 |  |  | 0x1C,
188 |  |  |  | 3 |  | 1 | 1 | 1 |  | 1 |  |  | 0x74,
189 |  |  |  | 4 | 1 | 1 | 1 | 1 | 1 | 1 |  |  | 0xFC,
190 |  |  |  | 5 |  |  | 1 |  |  | 1 |  |  | 0x24,
191 |  |  |  | 6 | 1 | 1 |  |  |  |  |  |  | 0xC0,
192 | 27 | 0x1B | Squid2R |  |  |  |  |  |  |  |  |  |  | { 0x00, 0xC0, 0x70, 0xF8, 0x20, 0x18, }, // 0x1B Squid2R
193 |  |  |  | 1 |  |  |  |  |  |  |  |  | 0x00,
194 |  |  |  | 2 | 1 | 1 |  |  |  |  |  |  | 0xC0,
195 |  |  |  | 3 |  | 1 | 1 | 1 |  |  |  |  | 0x70,
196 |  |  |  | 4 | 1 | 1 | 1 | 1 | 1 |  |  |  | 0xF8,
197 |  |  |  | 5 |  |  | 1 |  |  |  |  |  | 0x20,
198 |  |  |  | 6 |  |  |  | 1 | 1 |  |  |  | 0x18,
199 | 28 | 0x1C | UFO1L |  |  |  |  |  |  |  |  |  |  | { 0x1C, 0x7C, 0xCC, 0xFC, 0x38, 0x00, }, // 0x1C UFO1L
200 |  |  |  | 1 |  |  |  | 1 | 1 | 1 |  |  | 0x1C,
201 |  |  |  | 2 |  | 1 | 1 | 1 | 1 | 1 |  |  | 0x7C,
202 |  |  |  | 3 | 1 | 1 |  |  | 1 | 1 |  |  | 0xCC,
203 |  |  |  | 4 | 1 | 1 | 1 | 1 | 1 | 1 |  |  | 0xFC,
204 |  |  |  | 5 |  |  | 1 | 1 | 1 |  |  |  | 0x38,
205 |  |  |  | 6 |  |  |  |  |  |  |  |  | 0x00,
206 | 29 | 0x1D | UFO1R |  |  |  |  |  |  |  |  |  |  | { 0xE0, 0xF8, 0x3C, 0xFC, 0x70, 0x00, }, // 0x1D UFO1R
207 |  |  |  | 1 | 1 | 1 | 1 |  |  |  |  |  | 0xE0,
208 |  |  |  | 2 | 1 | 1 | 1 | 1 | 1 |  |  |  | 0xF8,
209 |  |  |  | 3 |  |  | 1 | 1 | 1 | 1 |  |  | 0x3C,
210 |  |  |  | 4 | 1 | 1 | 1 | 1 | 1 | 1 |  |  | 0xFC,
211 |  |  |  | 5 |  | 1 | 1 | 1 |  |  |  |  | 0x70,
212 |  |  |  | 6 |  |  |  |  |  |  |  |  | 0x00,
213 | 30 | 0x1E | UFO2L |  |  |  |  |  |  |  |  |  |  | { 0x1C, 0x7C, 0xF0, 0xFC, 0x38, 0x00, }, // 0x1E UFO2L
214 |  |  |  | 1 |  |  |  | 1 | 1 | 1 |  |  | 0x1C,
215 |  |  |  | 2 |  | 1 | 1 | 1 | 1 | 1 |  |  | 0x7C,
216 |  |  |  | 3 | 1 | 1 | 1 | 1 |  |  |  |  | 0xF0,
217 |  |  |  | 4 | 1 | 1 | 1 | 1 | 1 | 1 |  |  | 0xFC,
218 |  |  |  | 5 |  |  | 1 | 1 | 1 |  |  |  | 0x38,
219 |  |  |  | 6 |  |  |  |  |  |  |  |  | 0x00,
220 | 31 | 0x1F | UFO2R |  |  |  |  |  |  |  |  |  |  | { 0xE0, 0xF8, 0xCC, 0xFC, 0x70, 0x00, }, // 0x1F UFO2R
221 |  |  |  | 1 | 1 | 1 | 1 |  |  |  |  |  | 0xE0,
222 |  |  |  | 2 | 1 | 1 | 1 | 1 | 1 |  |  |  | 0xF8,
223 |  |  |  |  | 1 | 1 |  |  | 1 | 1 |  |  | 0xCC,
224 |  |  |  | 4 | 1 | 1 | 1 | 1 | 1 | 1 |  |  | 0xFC,
225 |  |  |  | 5 |  | 1 | 1 | 1 |  |  |  |  | 0x70,
226 |  |  |  | 6 |  |  |  |  |  |  |  |  | 0x00,
227 | 32 | 0x20 | space |  |  |  |  |  |  |  |  |  |  | { 0x00, 0x00, 0x00, 0x00, 0x00, 0x00, }, // 0x20 space
228 |  |  |  | 1 |  |  |  |  |  |  |  |  | 0x00,
229 |  |  |  | 2 |  |  |  |  |  |  |  |  | 0x00,
230 |  |  |  | 3 |  |  |  |  |  |  |  |  | 0x00,
231 |  |  |  | 4 |  |  |  |  |  |  |  |  | 0x00,
232 |  |  |  | 5 |  |  |  |  |  |  |  |  | 0x00,
233 |  |  |  | 6 |  |  |  |  |  |  |  |  | 0x00,
234 | 33 | 0x21 | ! |  |  |  |  |  |  |  |  |  |  | { 0x20, 0x20, 0x20, 0x00, 0x20, 0x00, }, // 0x21 !
235 |  |  |  | 1 |  |  | 1 |  |  |  |  |  | 0x20,
236 |  |  |  | 2 |  |  | 1 |  |  |  |  |  | 0x20,
237 |  |  |  | 3 |  |  | 1 |  |  |  |  |  | 0x20,
238 |  |  |  | 4 |  |  |  |  |  |  |  |  | 0x00,
239 |  |  |  | 5 |  |  | 1 |  |  |  |  |  | 0x20,
240 |  |  |  | 6 |  |  |  |  |  |  |  |  | 0x00,
241 | 34 | 0x22 | " |  |  |  |  |  |  |  |  |  |  | { 0x50, 0x50, 0x00, 0x00, 0x00, 0x00, }, // 0x22 "
242 |  |  |  | 1 |  | 1 |  | 1 |  |  |  |  | 0x50,
243 |  |  |  | 2 |  | 1 |  | 1 |  |  |  |  | 0x50,
244 |  |  |  | 3 |  |  |  |  |  |  |  |  | 0x00,
245 |  |  |  | 4 |  |  |  |  |  |  |  |  | 0x00,
246 |  |  |  | 5 |  |  |  |  |  |  |  |  | 0x00,
247 |  |  |  | 6 |  |  |  |  |  |  |  |  | 0x00,
248 | 35 | 0x23 | # |  |  |  |  |  |  |  |  |  |  | { 0x50, 0xF8, 0x50, 0xF8, 0x50, 0x00, }, // 0x23 #
249 |  |  |  | 1 |  | 1 |  | 1 |  |  |  |  | 0x50,
250 |  |  |  | 2 | 1 | 1 | 1 | 1 | 1 |  |  |  | 0xF8,
251 |  |  |  | 3 |  | 1 |  | 1 |  |  |  |  | 0x50,
252 |  |  |  | 4 | 1 | 1 | 1 | 1 | 1 |  |  |  | 0xF8,
253 |  |  |  | 5 |  | 1 |  | 1 |  |  |  |  | 0x50,
254 |  |  |  | 6 |  |  |  |  |  |  |  |  | 0x00,
255 | 36 | 0x24 | $ |  |  |  |  |  |  |  |  |  |  | { 0x78, 0xA0, 0x70, 0x28, 0xF0, 0x00, }, // 0x24 $
256 |  |  |  | 1 |  | 1 | 1 | 1 | 1 |  |  |  | 0x78,
257 |  |  |  | 2 | 1 |  | 1 |  |  |  |  |  | 0xA0,
258 |  |  |  | 3 |  | 1 | 1 | 1 |  |  |  |  | 0x70,
259 |  |  |  | 4 |  |  | 1 |  | 1 |  |  |  | 0x28,
260 |  |  |  | 5 | 1 | 1 | 1 | 1 |  |  |  |  | 0xF0,
261 |  |  |  | 6 |  |  |  |  |  |  |  |  | 0x00,
262 | 37 | 0x25 | % |  |  |  |  |  |  |  |  |  |  | { 0xC8, 0xD0, 0x20, 0x58, 0x98, 0x00, }, // 0x25 %
263 |  |  |  | 1 | 1 | 1 |  |  | 1 |  |  |  | 0xC8,
264 |  |  |  | 2 | 1 | 1 |  | 1 |  |  |  |  | 0xD0,
265 |  |  |  | 3 |  |  | 1 |  |  |  |  |  | 0x20,
266 |  |  |  | 4 |  | 1 |  | 1 | 1 |  |  |  | 0x58,
267 |  |  |  | 5 | 1 |  |  | 1 | 1 |  |  |  | 0x98,
268 |  |  |  | 6 |  |  |  |  |  |  |  |  | 0x00,
269 | 38 | 0x26 | & |  |  |  |  |  |  |  |  |  |  | { 0x40, 0xA0, 0x48, 0x90, 0x68, 0x00, }, // 0x26 &
270 |  |  |  | 1 |  | 1 |  |  |  |  |  |  | 0x40,
271 |  |  |  | 2 | 1 |  | 1 |  |  |  |  |  | 0xA0,
272 |  |  |  | 3 |  | 1 |  |  | 1 |  |  |  | 0x48,
273 |  |  |  | 4 | 1 |  |  | 1 |  |  |  |  | 0x90,
274 |  |  |  | 5 |  | 1 | 1 |  | 1 |  |  |  | 0x68,
275 |  |  |  | 6 |  |  |  |  |  |  |  |  | 0x00,
276 | 39 | 0x27 | ' |  |  |  |  |  |  |  |  |  |  | { 0x20, 0x20, 0x00, 0x00, 0x00, 0x00, }, // 0x27 '
277 |  |  |  | 1 |  |  | 1 |  |  |  |  |  | 0x20,
278 |  |  |  | 2 |  |  | 1 |  |  |  |  |  | 0x20,
279 |  |  |  | 3 |  |  |  |  |  |  |  |  | 0x00,
280 |  |  |  | 4 |  |  |  |  |  |  |  |  | 0x00,
281 |  |  |  | 5 |  |  |  |  |  |  |  |  | 0x00,
282 |  |  |  | 6 |  |  |  |  |  |  |  |  | 0x00,
283 | 40 | 0x28 | ( |  |  |  |  |  |  |  |  |  |  | { 0x10, 0x20, 0x20, 0x20, 0x10, 0x00, }, // 0x28 (
284 |  |  |  | 1 |  |  |  | 1 |  |  |  |  | 0x10,
285 |  |  |  | 2 |  |  | 1 |  |  |  |  |  | 0x20,
286 |  |  |  | 3 |  |  | 1 |  |  |  |  |  | 0x20,
287 |  |  |  | 4 |  |  | 1 |  |  |  |  |  | 0x20,
288 |  |  |  | 5 |  |  |  | 1 |  |  |  |  | 0x10,
289 |  |  |  | 6 |  |  |  |  |  |  |  |  | 0x00,
290 | 41 | 0x29 | ) |  |  |  |  |  |  |  |  |  |  | { 0x40, 0x20, 0x20, 0x20, 0x40, 0x00, }, // 0x29 )
291 |  |  |  | 1 |  | 1 |  |  |  |  |  |  | 0x40,
292 |  |  |  | 2 |  |  | 1 |  |  |  |  |  | 0x20,
293 |  |  |  | 3 |  |  | 1 |  |  |  |  |  | 0x20,
294 |  |  |  | 4 |  |  | 1 |  |  |  |  |  | 0x20,
295 |  |  |  | 5 |  | 1 |  |  |  |  |  |  | 0x40,
296 |  |  |  | 6 |  |  |  |  |  |  |  |  | 0x00,
297 | 42 | 0x2A | * |  |  |  |  |  |  |  |  |  |  | { 0xA8, 0x70, 0x20, 0x70, 0xA8, 0x00, }, // 0x2A *
298 |  |  |  | 1 | 1 |  | 1 |  | 1 |  |  |  | 0xA8,
299 |  |  |  | 2 |  | 1 | 1 | 1 |  |  |  |  | 0x70,
300 |  |  |  | 3 |  |  | 1 |  |  |  |  |  | 0x20,
301 |  |  |  | 4 |  | 1 | 1 | 1 |  |  |  |  | 0x70,
302 |  |  |  | 5 | 1 |  | 1 |  | 1 |  |  |  | 0xA8,
303 |  |  |  | 6 |  |  |  |  |  |  |  |  | 0x00,
304 | 43 | 0x2B | + |  |  |  |  |  |  |  |  |  |  | { 0x20, 0x20, 0xF8, 0x20, 0x20, 0x00, }, // 0x2B +
305 |  |  |  | 1 |  |  | 1 |  |  |  |  |  | 0x20,
306 |  |  |  | 2 |  |  | 1 |  |  |  |  |  | 0x20,
307 |  |  |  | 3 | 1 | 1 | 1 | 1 | 1 |  |  |  | 0xF8,
308 |  |  |  | 4 |  |  | 1 |  |  |  |  |  | 0x20,
309 |  |  |  | 5 |  |  | 1 |  |  |  |  |  | 0x20,
310 |  |  |  | 6 |  |  |  |  |  |  |  |  | 0x00,
311 | 44 | 0x2C | , |  |  |  |  |  |  |  |  |  |  | { 0x00, 0x00, 0x00, 0x00, 0x40, 0x80, }, // 0x2C ,
312 |  |  |  | 1 |  |  |  |  |  |  |  |  | 0x00,
313 |  |  |  | 2 |  |  |  |  |  |  |  |  | 0x00,
314 |  |  |  | 3 |  |  |  |  |  |  |  |  | 0x00,
315 |  |  |  | 4 |  |  |  |  |  |  |  |  | 0x00,
316 |  |  |  | 5 |  | 1 |  |  |  |  |  |  | 0x40,
317 |  |  |  | 6 | 1 |  |  |  |  |  |  |  | 0x80,
318 | 45 | 0x2D | - |  |  |  |  |  |  |  |  |  |  | { 0x00, 0x00, 0xF8, 0x00, 0x00, 0x00, }, // 0x2D -
319 |  |  |  | 1 |  |  |  |  |  |  |  |  | 0x00,
320 |  |  |  | 2 |  |  |  |  |  |  |  |  | 0x00,
321 |  |  |  | 3 | 1 | 1 | 1 | 1 | 1 |  |  |  | 0xF8,
322 |  |  |  | 4 |  |  |  |  |  |  |  |  | 0x00,
323 |  |  |  | 5 |  |  |  |  |  |  |  |  | 0x00,
324 |  |  |  | 6 |  |  |  |  |  |  |  |  | 0x00,
325 | 46 | 0x2E | . |  |  |  |  |  |  |  |  |  |  | { 0x00, 0x00, 0x00, 0x00, 0x40, 0x00, }, // 0x2E .
326 |  |  |  | 1 |  |  |  |  |  |  |  |  | 0x00,
327 |  |  |  | 2 |  |  |  |  |  |  |  |  | 0x00,
328 |  |  |  | 3 |  |  |  |  |  |  |  |  | 0x00,
329 |  |  |  | 4 |  |  |  |  |  |  |  |  | 0x00,
330 |  |  |  | 5 |  | 1 |  |  |  |  |  |  | 0x40,
331 |  |  |  | 6 |  |  |  |  |  |  |  |  | 0x00,
332 | 47 | 0x2F | / |  |  |  |  |  |  |  |  |  |  | { 0x08, 0x10, 0x20, 0x40, 0x80, 0x00, }, // 0x2F /
333 |  |  |  | 1 |  |  |  |  | 1 |  |  |  | 0x08,
334 |  |  |  | 2 |  |  |  | 1 |  |  |  |  | 0x10,
335 |  |  |  | 3 |  |  | 1 |  |  |  |  |  | 0x20,
336 |  |  |  | 4 |  | 1 |  |  |  |  |  |  | 0x40,
337 |  |  |  | 5 | 1 |  |  |  |  |  |  |  | 0x80,
338 |  |  |  | 6 |  |  |  |  |  |  |  |  | 0x00,
339 | 48 | 0x30 | 0 |  |  |  |  |  |  |  |  |  |  | { 0x70, 0x98, 0xA8, 0xC8, 0x70, 0x00, }, // 0x30 0
340 |  |  |  | 1 |  | 1 | 1 | 1 |  |  |  |  | 0x70,
341 |  |  |  | 2 | 1 |  |  | 1 | 1 |  |  |  | 0x98,
342 |  |  |  | 3 | 1 |  | 1 |  | 1 |  |  |  | 0xA8,
343 |  |  |  | 4 | 1 | 1 |  |  | 1 |  |  |  | 0xC8,
344 |  |  |  | 5 |  | 1 | 1 | 1 |  |  |  |  | 0x70,
345 |  |  |  | 6 |  |  |  |  |  |  |  |  | 0x00,
346 | 49 | 0x31 | 1 |  |  |  |  |  |  |  |  |  |  | { 0x20, 0x60, 0x20, 0x20, 0x70, 0x00, }, // 0x31 1
347 |  |  |  | 1 |  |  | 1 |  |  |  |  |  | 0x20,
348 |  |  |  | 2 |  | 1 | 1 |  |  |  |  |  | 0x60,
349 |  |  |  | 3 |  |  | 1 |  |  |  |  |  | 0x20,
350 |  |  |  | 4 |  |  | 1 |  |  |  |  |  | 0x20,
351 |  |  |  | 5 |  | 1 | 1 | 1 |  |  |  |  | 0x70,
352 |  |  |  | 6 |  |  |  |  |  |  |  |  | 0x00,
353 | 50 | 0x32 | 2 |  |  |  |  |  |  |  |  |  |  | { 0xF0, 0x08, 0x70, 0x80, 0xF8, 0x00, }, // 0x32 2
354 |  |  |  | 1 | 1 | 1 | 1 | 1 |  |  |  |  | 0xF0,
355 |  |  |  | 2 |  |  |  |  | 1 |  |  |  | 0x08,
356 |  |  |  | 3 |  | 1 | 1 | 1 |  |  |  |  | 0x70,
357 |  |  |  | 4 | 1 |  |  |  |  |  |  |  | 0x80,
358 |  |  |  | 5 | 1 | 1 | 1 | 1 | 1 |  |  |  | 0xF8,
359 |  |  |  | 6 |  |  |  |  |  |  |  |  | 0x00,
360 | 51 | 0x33 | 3 |  |  |  |  |  |  |  |  |  |  | { 0xF0, 0x08, 0x70, 0x08, 0xF0, 0x00, }, // 0x33 3
361 |  |  |  | 1 | 1 | 1 | 1 | 1 |  |  |  |  | 0xF0,
362 |  |  |  | 2 |  |  |  |  | 1 |  |  |  | 0x08,
363 |  |  |  | 3 |  | 1 | 1 | 1 |  |  |  |  | 0x70,
364 |  |  |  | 4 |  |  |  |  | 1 |  |  |  | 0x08,
365 |  |  |  | 5 | 1 | 1 | 1 | 1 |  |  |  |  | 0xF0,
366 |  |  |  | 6 |  |  |  |  |  |  |  |  | 0x00,
367 | 52 | 0x34 | 4 |  |  |  |  |  |  |  |  |  |  | { 0x30, 0x50, 0x90, 0xF8, 0x10, 0x00, }, // 0x34 4
368 |  |  |  | 1 |  |  | 1 | 1 |  |  |  |  | 0x30,
369 |  |  |  | 2 |  | 1 |  | 1 |  |  |  |  | 0x50,
370 |  |  |  | 3 | 1 |  |  | 1 |  |  |  |  | 0x90,
371 |  |  |  | 4 | 1 | 1 | 1 | 1 | 1 |  |  |  | 0xF8,
372 |  |  |  | 5 |  |  |  | 1 |  |  |  |  | 0x10,
373 |  |  |  | 6 |  |  |  |  |  |  |  |  | 0x00,
374 | 53 | 0x35 | 5 |  |  |  |  |  |  |  |  |  |  | { 0xF8, 0x80, 0xF0, 0x08, 0xF0, 0x00, }, // 0x35 5
375 |  |  |  | 1 | 1 | 1 | 1 | 1 | 1 |  |  |  | 0xF8,
376 |  |  |  | 2 | 1 |  |  |  |  |  |  |  | 0x80,
377 |  |  |  | 3 | 1 | 1 | 1 | 1 |  |  |  |  | 0xF0,
378 |  |  |  | 4 |  |  |  |  | 1 |  |  |  | 0x08,
379 |  |  |  | 5 | 1 | 1 | 1 | 1 |  |  |  |  | 0xF0,
380 |  |  |  | 6 |  |  |  |  |  |  |  |  | 0x00,
381 | 54 | 0x36 | 6 |  |  |  |  |  |  |  |  |  |  | { 0x70, 0x80, 0xF0, 0x88, 0x70, 0x00, }, // 0x36 6
382 |  |  |  | 1 |  | 1 | 1 | 1 |  |  |  |  | 0x70,
383 |  |  |  | 2 | 1 |  |  |  |  |  |  |  | 0x80,
384 |  |  |  | 3 | 1 | 1 | 1 | 1 |  |  |  |  | 0xF0,
385 |  |  |  | 4 | 1 |  |  |  | 1 |  |  |  | 0x88,
386 |  |  |  | 5 |  | 1 | 1 | 1 |  |  |  |  | 0x70,
387 |  |  |  | 6 |  |  |  |  |  |  |  |  | 0x00,
388 | 55 | 0x37 | 7 |  |  |  |  |  |  |  |  |  |  | { 0xF8, 0x08, 0x10, 0x20, 0x20, 0x00, }, // 0x37 7
389 |  |  |  | 1 | 1 | 1 | 1 | 1 | 1 |  |  |  | 0xF8,
390 |  |  |  | 2 |  |  |  |  | 1 |  |  |  | 0x08,
391 |  |  |  | 3 |  |  |  | 1 |  |  |  |  | 0x10,
392 |  |  |  | 4 |  |  | 1 |  |  |  |  |  | 0x20,
393 |  |  |  | 5 |  |  | 1 |  |  |  |  |  | 0x20,
394 |  |  |  | 6 |  |  |  |  |  |  |  |  | 0x00,
395 | 56 | 0x38 | 8 |  |  |  |  |  |  |  |  |  |  | { 0x70, 0x88, 0x70, 0x88, 0x70, 0x00, }, // 0x38 8
396 |  |  |  | 1 |  | 1 | 1 | 1 |  |  |  |  | 0x70,
397 |  |  |  | 2 | 1 |  |  |  | 1 |  |  |  | 0x88,
398 |  |  |  | 3 |  | 1 | 1 | 1 |  |  |  |  | 0x70,
399 |  |  |  | 4 | 1 |  |  |  | 1 |  |  |  | 0x88,
400 |  |  |  | 5 |  | 1 | 1 | 1 |  |  |  |  | 0x70,
401 |  |  |  | 6 |  |  |  |  |  |  |  |  | 0x00,
402 | 57 | 0x39 | 9 |  |  |  |  |  |  |  |  |  |  | { 0x70, 0x88, 0x78, 0x08, 0x70, 0x00, }, // 0x39 9
403 |  |  |  | 1 |  | 1 | 1 | 1 |  |  |  |  | 0x70,
404 |  |  |  | 2 | 1 |  |  |  | 1 |  |  |  | 0x88,
405 |  |  |  | 3 |  | 1 | 1 | 1 | 1 |  |  |  | 0x78,
406 |  |  |  | 4 |  |  |  |  | 1 |  |  |  | 0x08,
407 |  |  |  | 5 |  | 1 | 1 | 1 |  |  |  |  | 0x70,
408 |  |  |  | 6 |  |  |  |  |  |  |  |  | 0x00,
409 | 58 | 0x3A | : |  |  |  |  |  |  |  |  |  |  | { 0x00, 0x20, 0x00, 0x20, 0x00, 0x00, }, // 0x3A :
410 |  |  |  | 1 |  |  |  |  |  |  |  |  | 0x00,
411 |  |  |  | 2 |  |  | 1 |  |  |  |  |  | 0x20,
412 |  |  |  | 3 |  |  |  |  |  |  |  |  | 0x00,
413 |  |  |  | 4 |  |  | 1 |  |  |  |  |  | 0x20,
414 |  |  |  | 5 |  |  |  |  |  |  |  |  | 0x00,
415 |  |  |  | 6 |  |  |  |  |  |  |  |  | 0x00,
416 | 59 | 0x3B | ; |  |  |  |  |  |  |  |  |  |  | { 0x00, 0x20, 0x00, 0x20, 0x40, 0x00, }, // 0x3B ;
417 |  |  |  | 1 |  |  |  |  |  |  |  |  | 0x00,
418 |  |  |  | 2 |  |  | 1 |  |  |  |  |  | 0x20,
419 |  |  |  | 3 |  |  |  |  |  |  |  |  | 0x00,
420 |  |  |  | 4 |  |  | 1 |  |  |  |  |  | 0x20,
421 |  |  |  | 5 |  | 1 |  |  |  |  |  |  | 0x40,
422 |  |  |  | 6 |  |  |  |  |  |  |  |  | 0x00,
423 | 60 | 0x3C | < |  |  |  |  |  |  |  |  |  |  | { 0x10, 0x20, 0x40, 0x20, 0x10, 0x00, }, // 0x3C <
424 |  |  |  | 1 |  |  |  | 1 |  |  |  |  | 0x10,
425 |  |  |  | 2 |  |  | 1 |  |  |  |  |  | 0x20,
426 |  |  |  | 3 |  | 1 |  |  |  |  |  |  | 0x40,
427 |  |  |  | 4 |  |  | 1 |  |  |  |  |  | 0x20,
428 |  |  |  | 5 |  |  |  | 1 |  |  |  |  | 0x10,
429 |  |  |  | 6 |  |  |  |  |  |  |  |  | 0x00,
430 | 61 | 0x3D | = |  |  |  |  |  |  |  |  |  |  | { 0x00, 0xF8, 0x00, 0xF8, 0x00, 0x00, }, // 0x3D =
431 |  |  |  | 1 |  |  |  |  |  |  |  |  | 0x00,
432 |  |  |  | 2 | 1 | 1 | 1 | 1 | 1 |  |  |  | 0xF8,
433 |  |  |  | 3 |  |  |  |  |  |  |  |  | 0x00,
434 |  |  |  | 4 | 1 | 1 | 1 | 1 | 1 |  |  |  | 0xF8,
435 |  |  |  | 5 |  |  |  |  |  |  |  |  | 0x00,
436 |  |  |  | 6 |  |  |  |  |  |  |  |  | 0x00,
437 | 62 | 0x3E | > |  |  |  |  |  |  |  |  |  |  | { 0x40, 0x20, 0x10, 0x20, 0x40, 0x00, }, // 0x3E >
438 |  |  |  | 1 |  | 1 |  |  |  |  |  |  | 0x40,
439 |  |  |  | 2 |  |  | 1 |  |  |  |  |  | 0x20,
440 |  |  |  | 3 |  |  |  | 1 |  |  |  |  | 0x10,
441 |  |  |  | 4 |  |  | 1 |  |  |  |  |  | 0x20,
442 |  |  |  | 5 |  | 1 |  |  |  |  |  |  | 0x40,
443 |  |  |  | 6 |  |  |  |  |  |  |  |  | 0x00,
444 | 63 | 0x3F | ? |  |  |  |  |  |  |  |  |  |  | { 0x70, 0x88, 0x30, 0x00, 0x20, 0x00, }, // 0x3F ?
445 |  |  |  | 1 |  | 1 | 1 | 1 |  |  |  |  | 0x70,
446 |  |  |  | 2 | 1 |  |  |  | 1 |  |  |  | 0x88,
447 |  |  |  | 3 |  |  | 1 | 1 |  |  |  |  | 0x30,
448 |  |  |  | 4 |  |  |  |  |  |  |  |  | 0x00,
449 |  |  |  | 5 |  |  | 1 |  |  |  |  |  | 0x20,
450 |  |  |  | 6 |  |  |  |  |  |  |  |  | 0x00,
451 | 64 | 0x40 | @ |  |  |  |  |  |  |  |  |  |  | { 0x70, 0x88, 0xB8, 0xA8, 0xB8, 0x00, }, // 0x40 @
452 |  |  |  | 1 |  | 1 | 1 | 1 |  |  |  |  | 0x70,
453 |  |  |  | 2 | 1 |  |  |  | 1 |  |  |  | 0x88,
454 |  |  |  | 3 | 1 |  | 1 | 1 | 1 |  |  |  | 0xB8,
455 |  |  |  | 4 | 1 |  | 1 |  | 1 |  |  |  | 0xA8,
456 |  |  |  | 5 | 1 |  | 1 | 1 | 1 |  |  |  | 0xB8,
457 |  |  |  | 6 |  |  |  |  |  |  |  |  | 0x00,
458 | 65 | 0x41 | A |  |  |  |  |  |  |  |  |  |  | { 0x20, 0x50, 0x88, 0xF8, 0x88, 0x00, }, // 0x41 A
459 |  |  |  | 1 |  |  | 1 |  |  |  |  |  | 0x20,
460 |  |  |  | 2 |  | 1 |  | 1 |  |  |  |  | 0x50,
461 |  |  |  | 3 | 1 |  |  |  | 1 |  |  |  | 0x88,
462 |  |  |  | 4 | 1 | 1 | 1 | 1 | 1 |  |  |  | 0xF8,
463 |  |  |  | 5 | 1 |  |  |  | 1 |  |  |  | 0x88,
464 |  |  |  | 6 |  |  |  |  |  |  |  |  | 0x00,
465 | 66 | 0x42 | B |  |  |  |  |  |  |  |  |  |  | { 0xF0, 0x48, 0x70, 0x48, 0xF0, 0x00, }, // 0x42 B
466 |  |  |  | 1 | 1 | 1 | 1 | 1 |  |  |  |  | 0xF0,
467 |  |  |  | 2 |  | 1 |  |  | 1 |  |  |  | 0x48,
468 |  |  |  | 3 |  | 1 | 1 | 1 |  |  |  |  | 0x70,
469 |  |  |  | 4 |  | 1 |  |  | 1 |  |  |  | 0x48,
470 |  |  |  | 5 | 1 | 1 | 1 | 1 |  |  |  |  | 0xF0,
471 |  |  |  | 6 |  |  |  |  |  |  |  |  | 0x00,
472 | 67 | 0x43 | C |  |  |  |  |  |  |  |  |  |  | { 0x78, 0x80, 0x80, 0x80, 0x78, 0x00, }, // 0x43 C
473 |  |  |  | 1 |  | 1 | 1 | 1 | 1 |  |  |  | 0x78,
474 |  |  |  | 2 | 1 |  |  |  |  |  |  |  | 0x80,
475 |  |  |  | 3 | 1 |  |  |  |  |  |  |  | 0x80,
476 |  |  |  | 4 | 1 |  |  |  |  |  |  |  | 0x80,
477 |  |  |  | 5 |  | 1 | 1 | 1 | 1 |  |  |  | 0x78,
478 |  |  |  | 6 |  |  |  |  |  |  |  |  | 0x00,
479 | 68 | 0x44 | D |  |  |  |  |  |  |  |  |  |  | { 0xF0, 0x48, 0x48, 0x48, 0xF0, 0x00, }, // 0x44 D
480 |  |  |  | 1 | 1 | 1 | 1 | 1 |  |  |  |  | 0xF0,
481 |  |  |  | 2 |  | 1 |  |  | 1 |  |  |  | 0x48,
482 |  |  |  | 3 |  | 1 |  |  | 1 |  |  |  | 0x48,
483 |  |  |  | 4 |  | 1 |  |  | 1 |  |  |  | 0x48,
484 |  |  |  | 5 | 1 | 1 | 1 | 1 |  |  |  |  | 0xF0,
485 |  |  |  | 6 |  |  |  |  |  |  |  |  | 0x00,
486 | 69 | 0x45 | E |  |  |  |  |  |  |  |  |  |  | { 0xF8, 0x80, 0xF0, 0x80, 0xF8, 0x00, }, // 0x45 E
487 |  |  |  | 1 | 1 | 1 | 1 | 1 | 1 |  |  |  | 0xF8,
488 |  |  |  | 2 | 1 |  |  |  |  |  |  |  | 0x80,
489 |  |  |  | 3 | 1 | 1 | 1 | 1 |  |  |  |  | 0xF0,
490 |  |  |  | 4 | 1 |  |  |  |  |  |  |  | 0x80,
491 |  |  |  | 5 | 1 | 1 | 1 | 1 | 1 |  |  |  | 0xF8,
492 |  |  |  | 6 |  |  |  |  |  |  |  |  | 0x00,
493 | 70 | 0x46 | F |  |  |  |  |  |  |  |  |  |  | { 0xF8, 0x80, 0xF0, 0x80, 0x80, 0x00, }, // 0x46 F
494 |  |  |  | 1 | 1 | 1 | 1 | 1 | 1 |  |  |  | 0xF8,
495 |  |  |  | 2 | 1 |  |  |  |  |  |  |  | 0x80,
496 |  |  |  | 3 | 1 | 1 | 1 | 1 |  |  |  |  | 0xF0,
497 |  |  |  | 4 | 1 |  |  |  |  |  |  |  | 0x80,
498 |  |  |  | 5 | 1 |  |  |  |  |  |  |  | 0x80,
499 |  |  |  | 6 |  |  |  |  |  |  |  |  | 0x00,
500 | 71 | 0x47 | G |  |  |  |  |  |  |  |  |  |  | { 0x78, 0x80, 0xB8, 0x88, 0x78, 0x00, }, // 0x47 G
501 |  |  |  | 1 |  | 1 | 1 | 1 | 1 |  |  |  | 0x78,
502 |  |  |  | 2 | 1 |  |  |  |  |  |  |  | 0x80,
503 |  |  |  | 3 | 1 |  | 1 | 1 | 1 |  |  |  | 0xB8,
504 |  |  |  | 4 | 1 |  |  |  | 1 |  |  |  | 0x88,
505 |  |  |  | 5 |  | 1 | 1 | 1 | 1 |  |  |  | 0x78,
506 |  |  |  | 6 |  |  |  |  |  |  |  |  | 0x00,
507 | 72 | 0x48 | H |  |  |  |  |  |  |  |  |  |  | { 0x88, 0x88, 0xF8, 0x88, 0x88, 0x00, }, // 0x48 H
508 |  |  |  | 1 | 1 |  |  |  | 1 |  |  |  | 0x88,
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

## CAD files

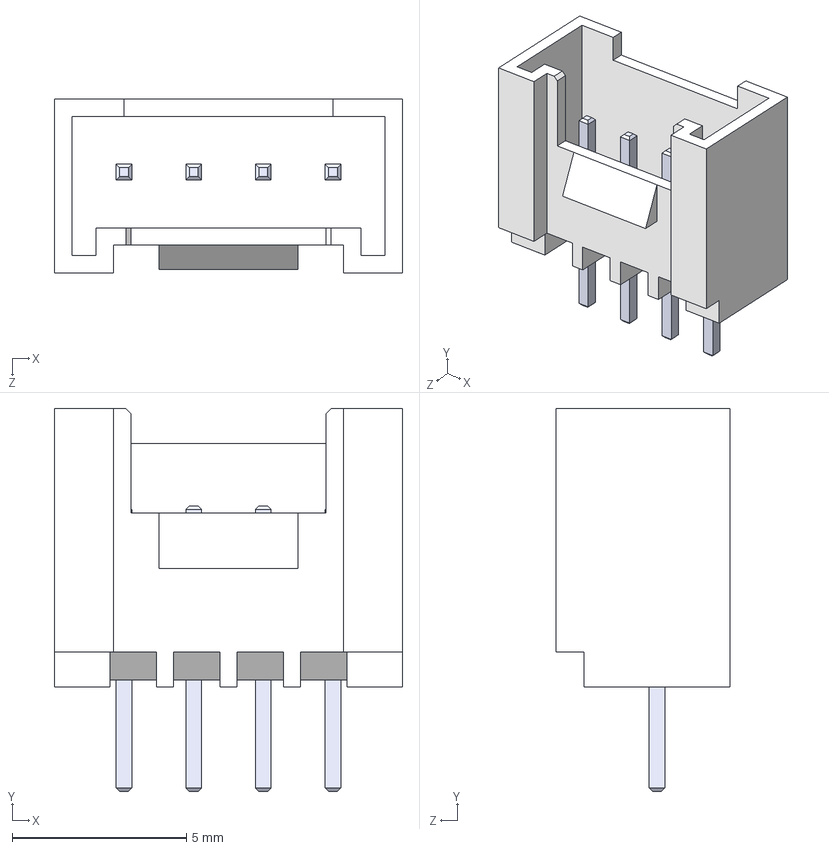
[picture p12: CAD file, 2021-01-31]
BF@kicad.3d/Grove Connector (standing).STEP
10.0 x 11.0 x 5.00 mm

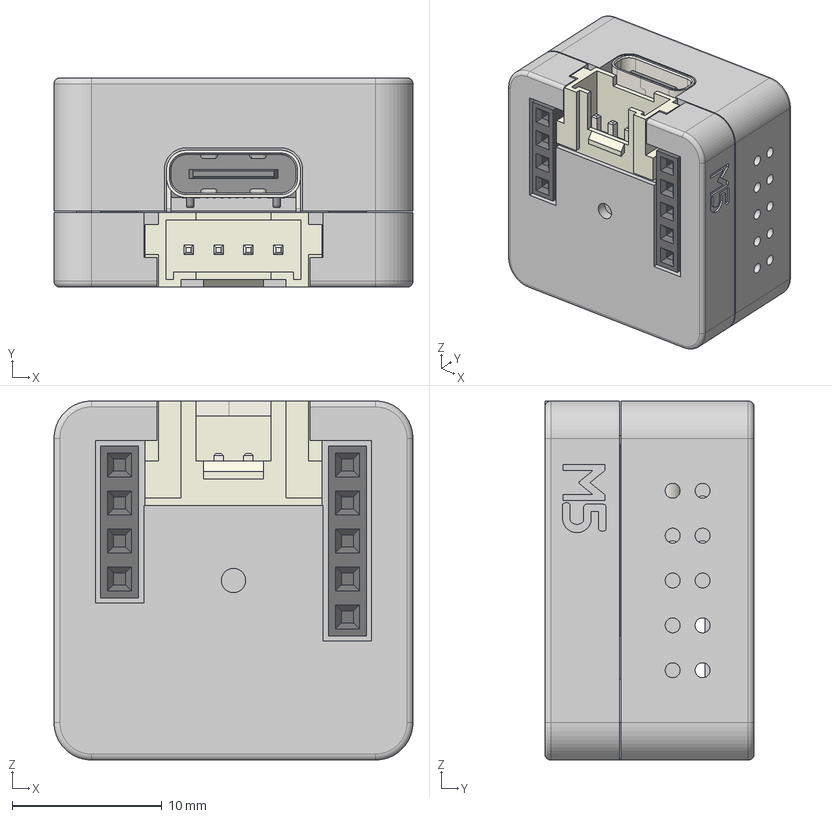
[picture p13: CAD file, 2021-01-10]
BF@kicad.3d/M5 ATOM Matrix.step
24.0 x 14.0 x 24.0 mm
Grove socket
pinsocket_5 v2
pinsocket_4 v3
ConPins
PcbPins
Mold
Frame

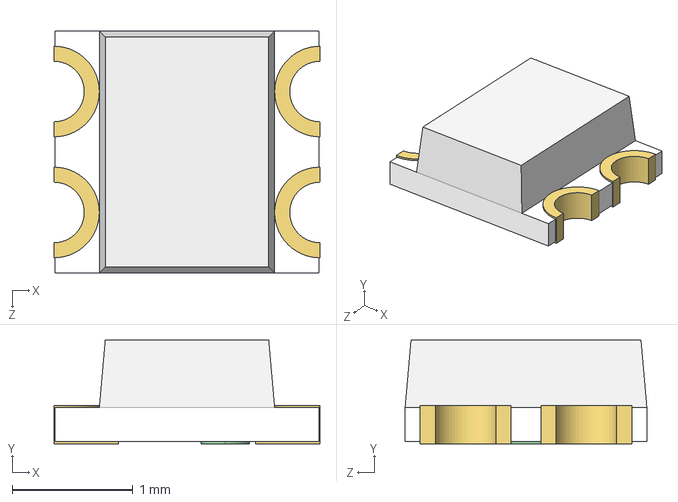
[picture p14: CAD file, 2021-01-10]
BF@kicad.3d/WS2812-2020.STEP
2.20 x 0.86 x 2.00 mm

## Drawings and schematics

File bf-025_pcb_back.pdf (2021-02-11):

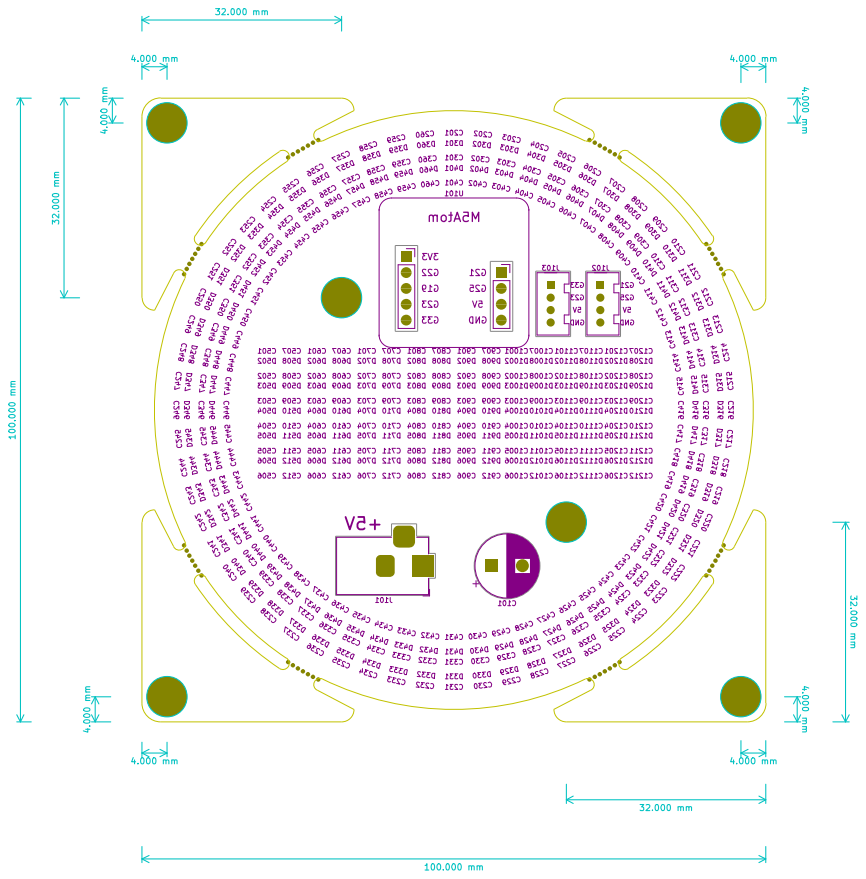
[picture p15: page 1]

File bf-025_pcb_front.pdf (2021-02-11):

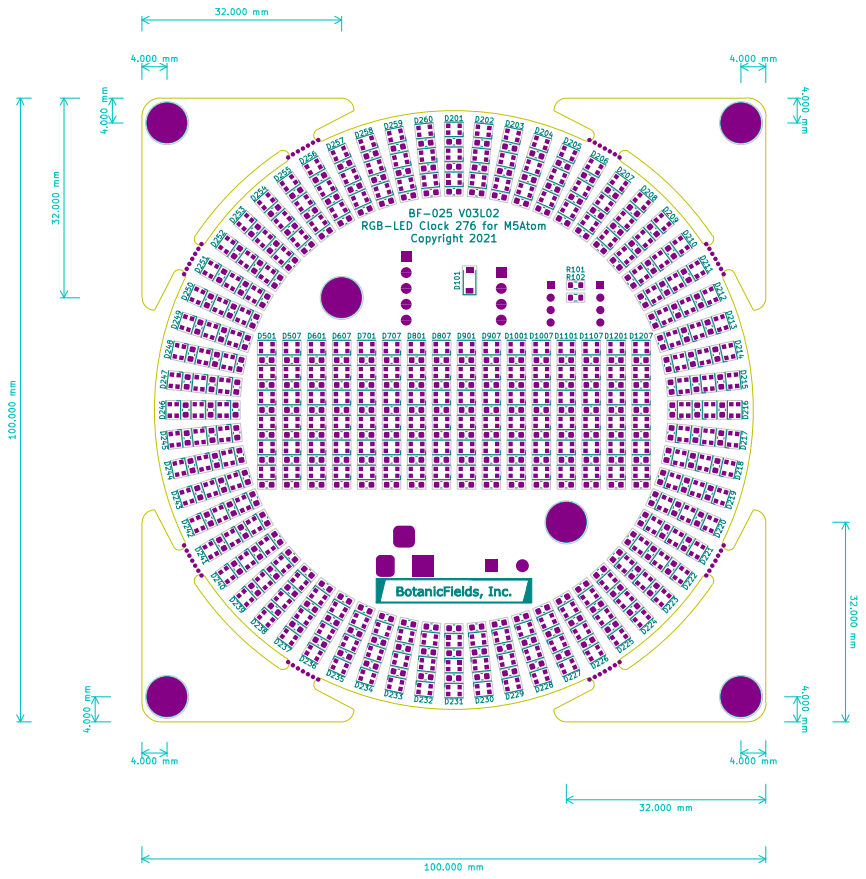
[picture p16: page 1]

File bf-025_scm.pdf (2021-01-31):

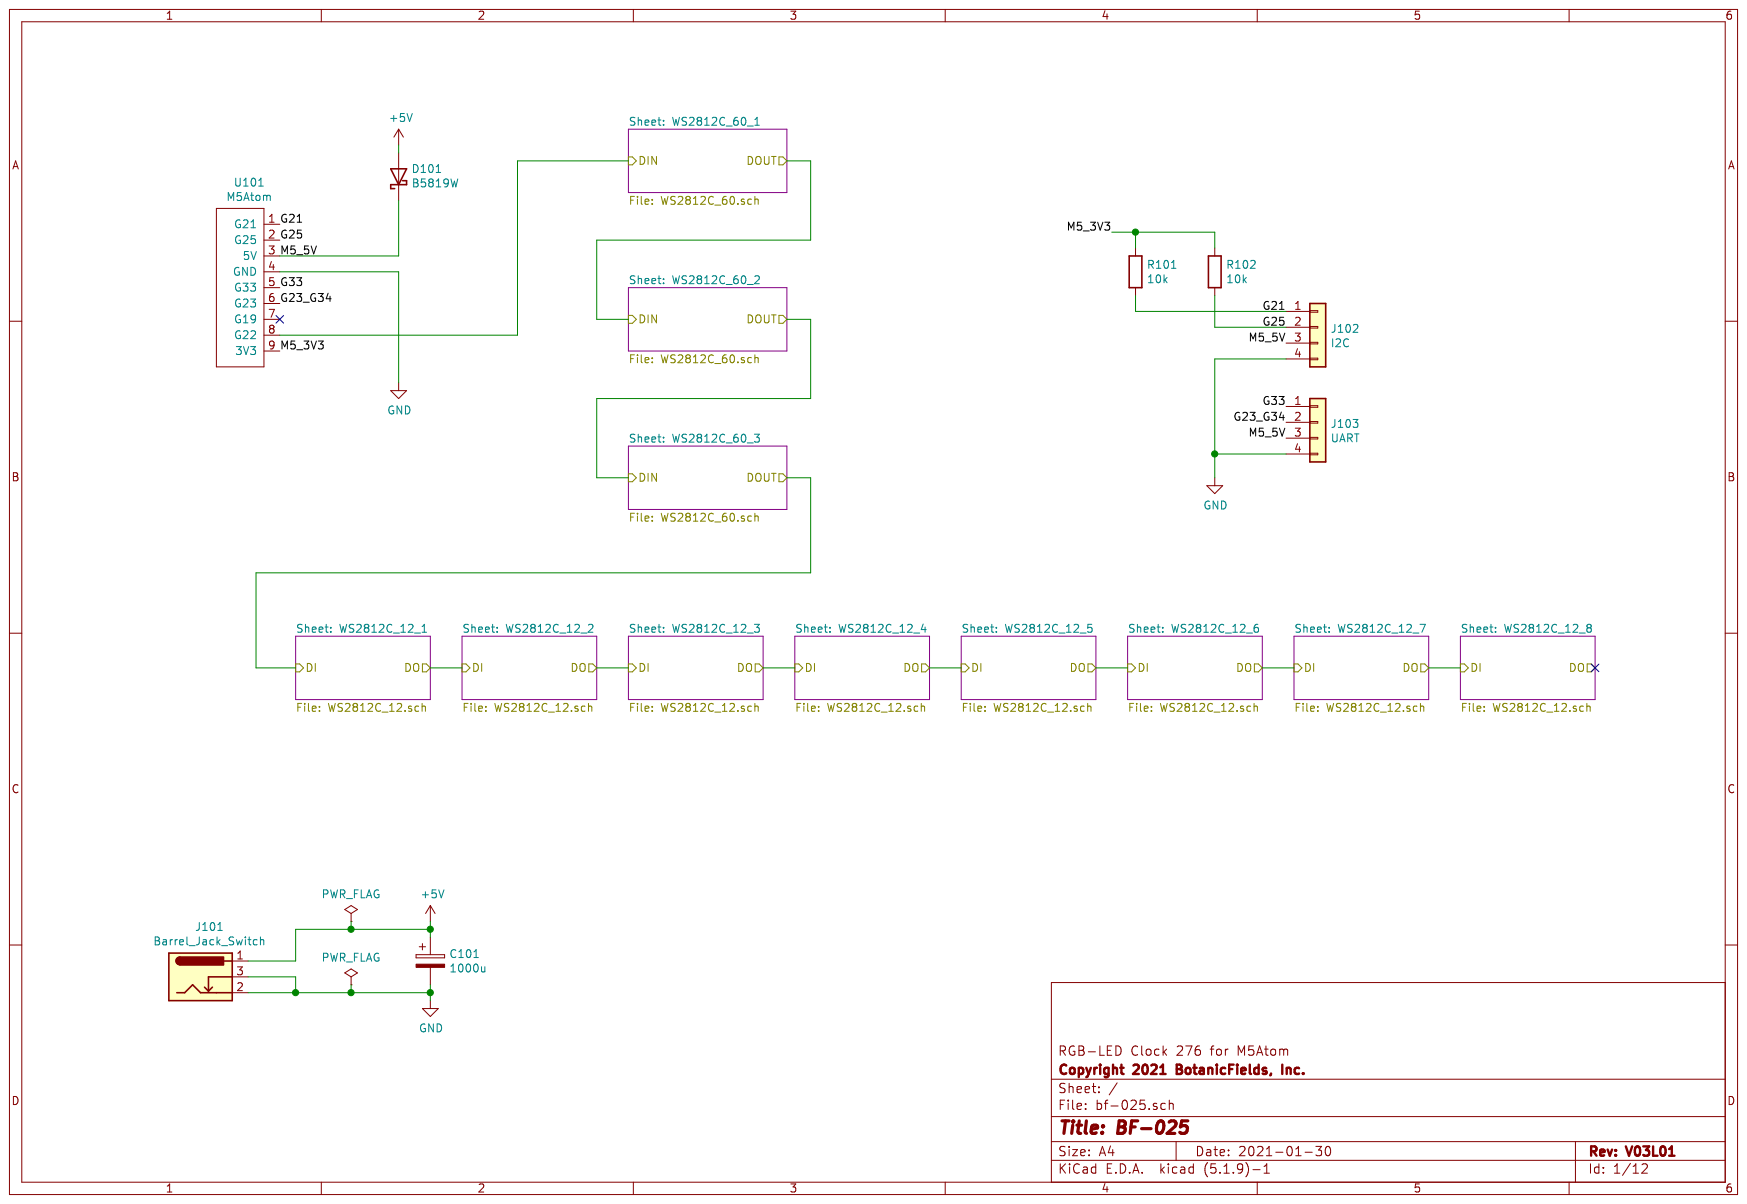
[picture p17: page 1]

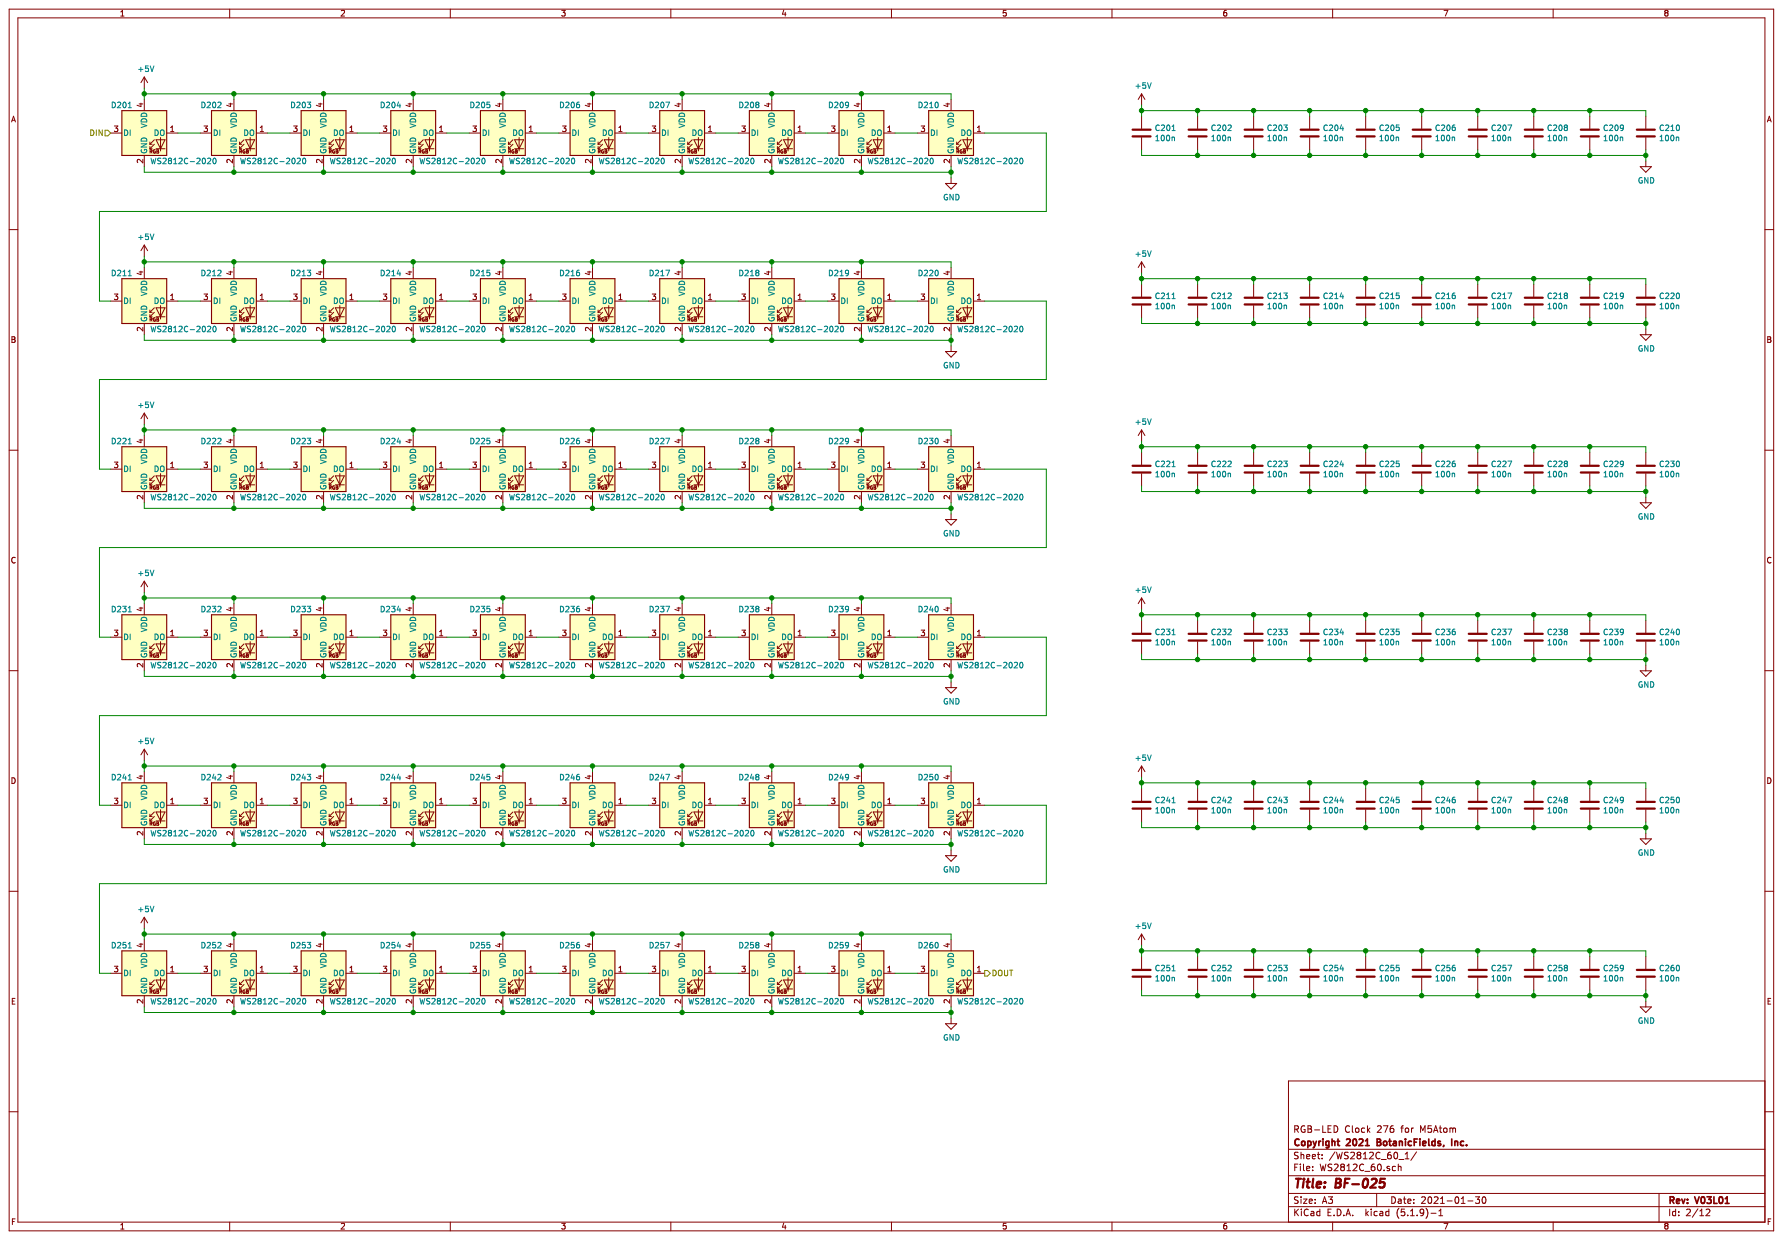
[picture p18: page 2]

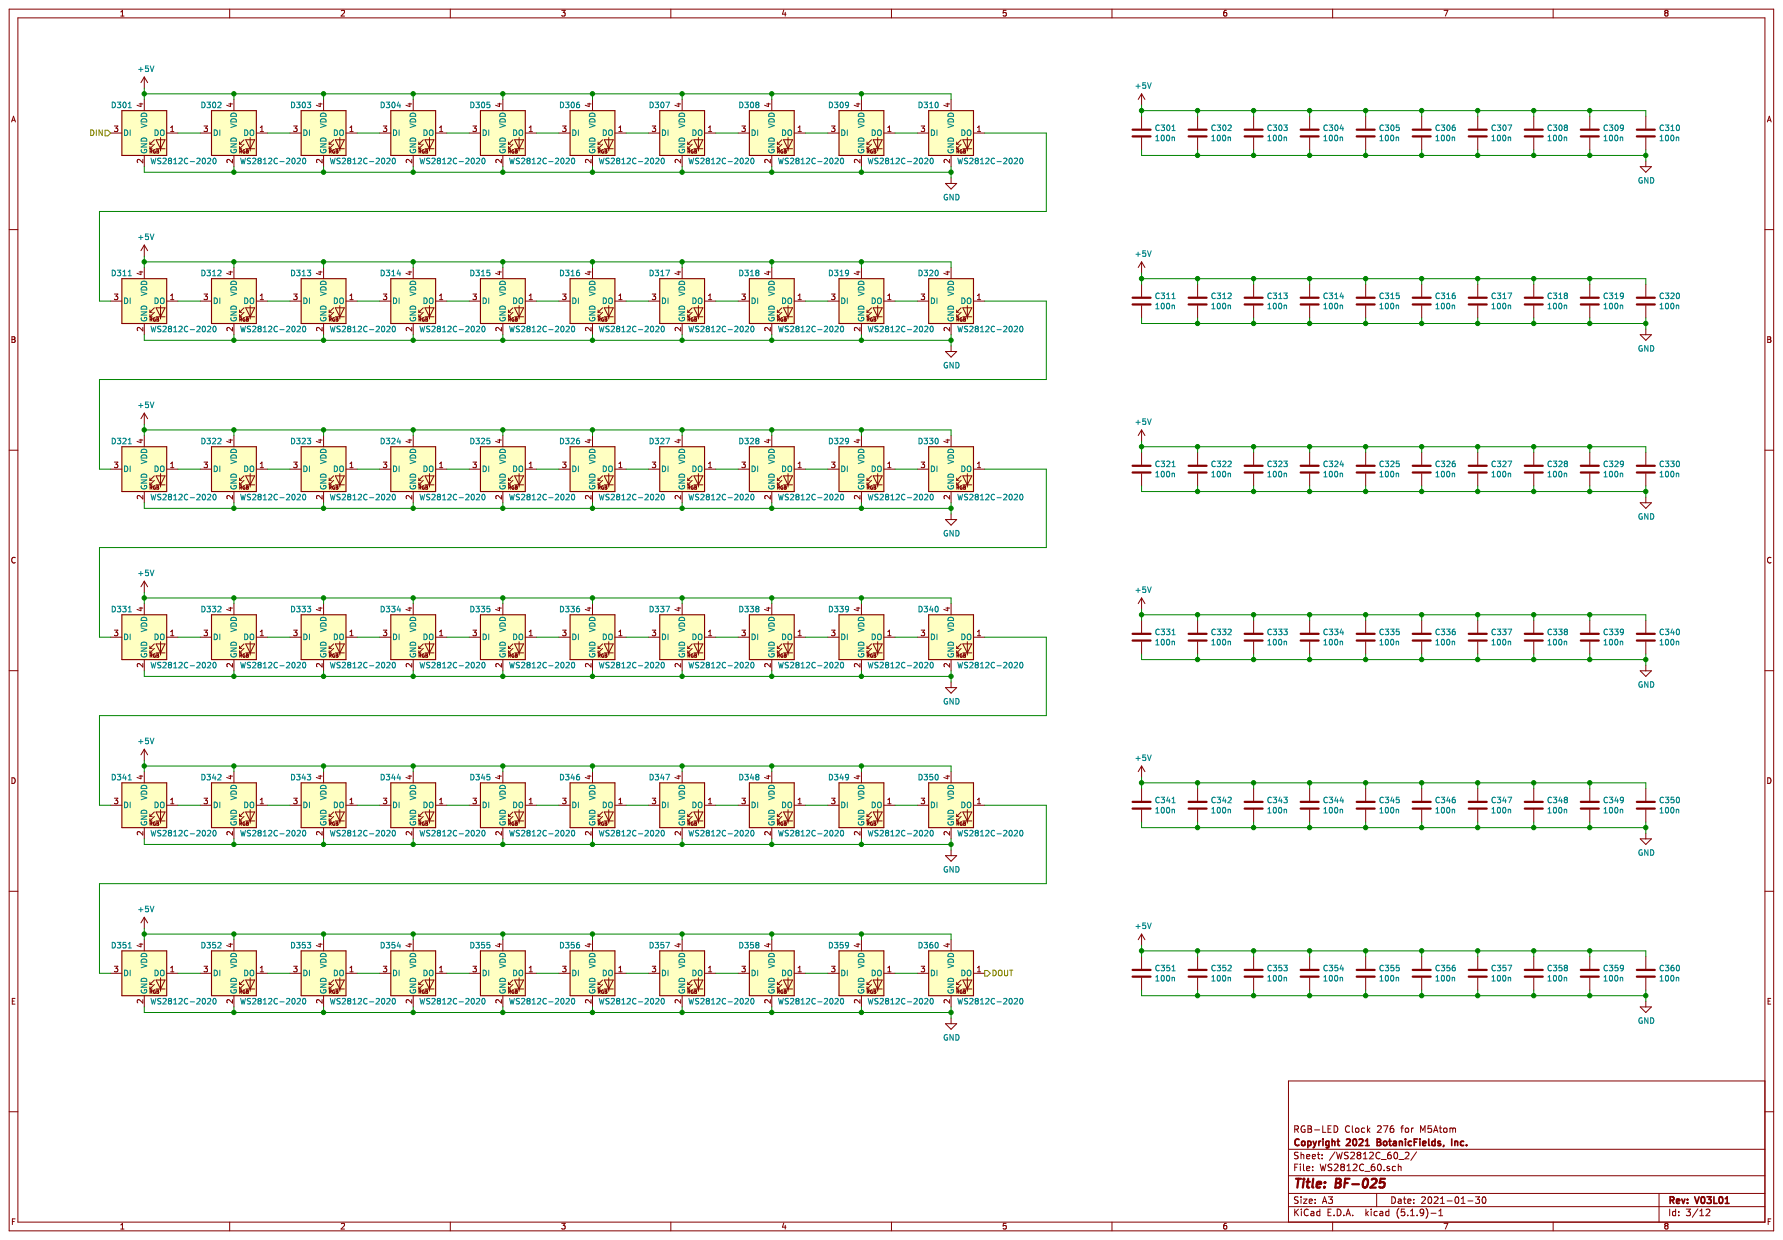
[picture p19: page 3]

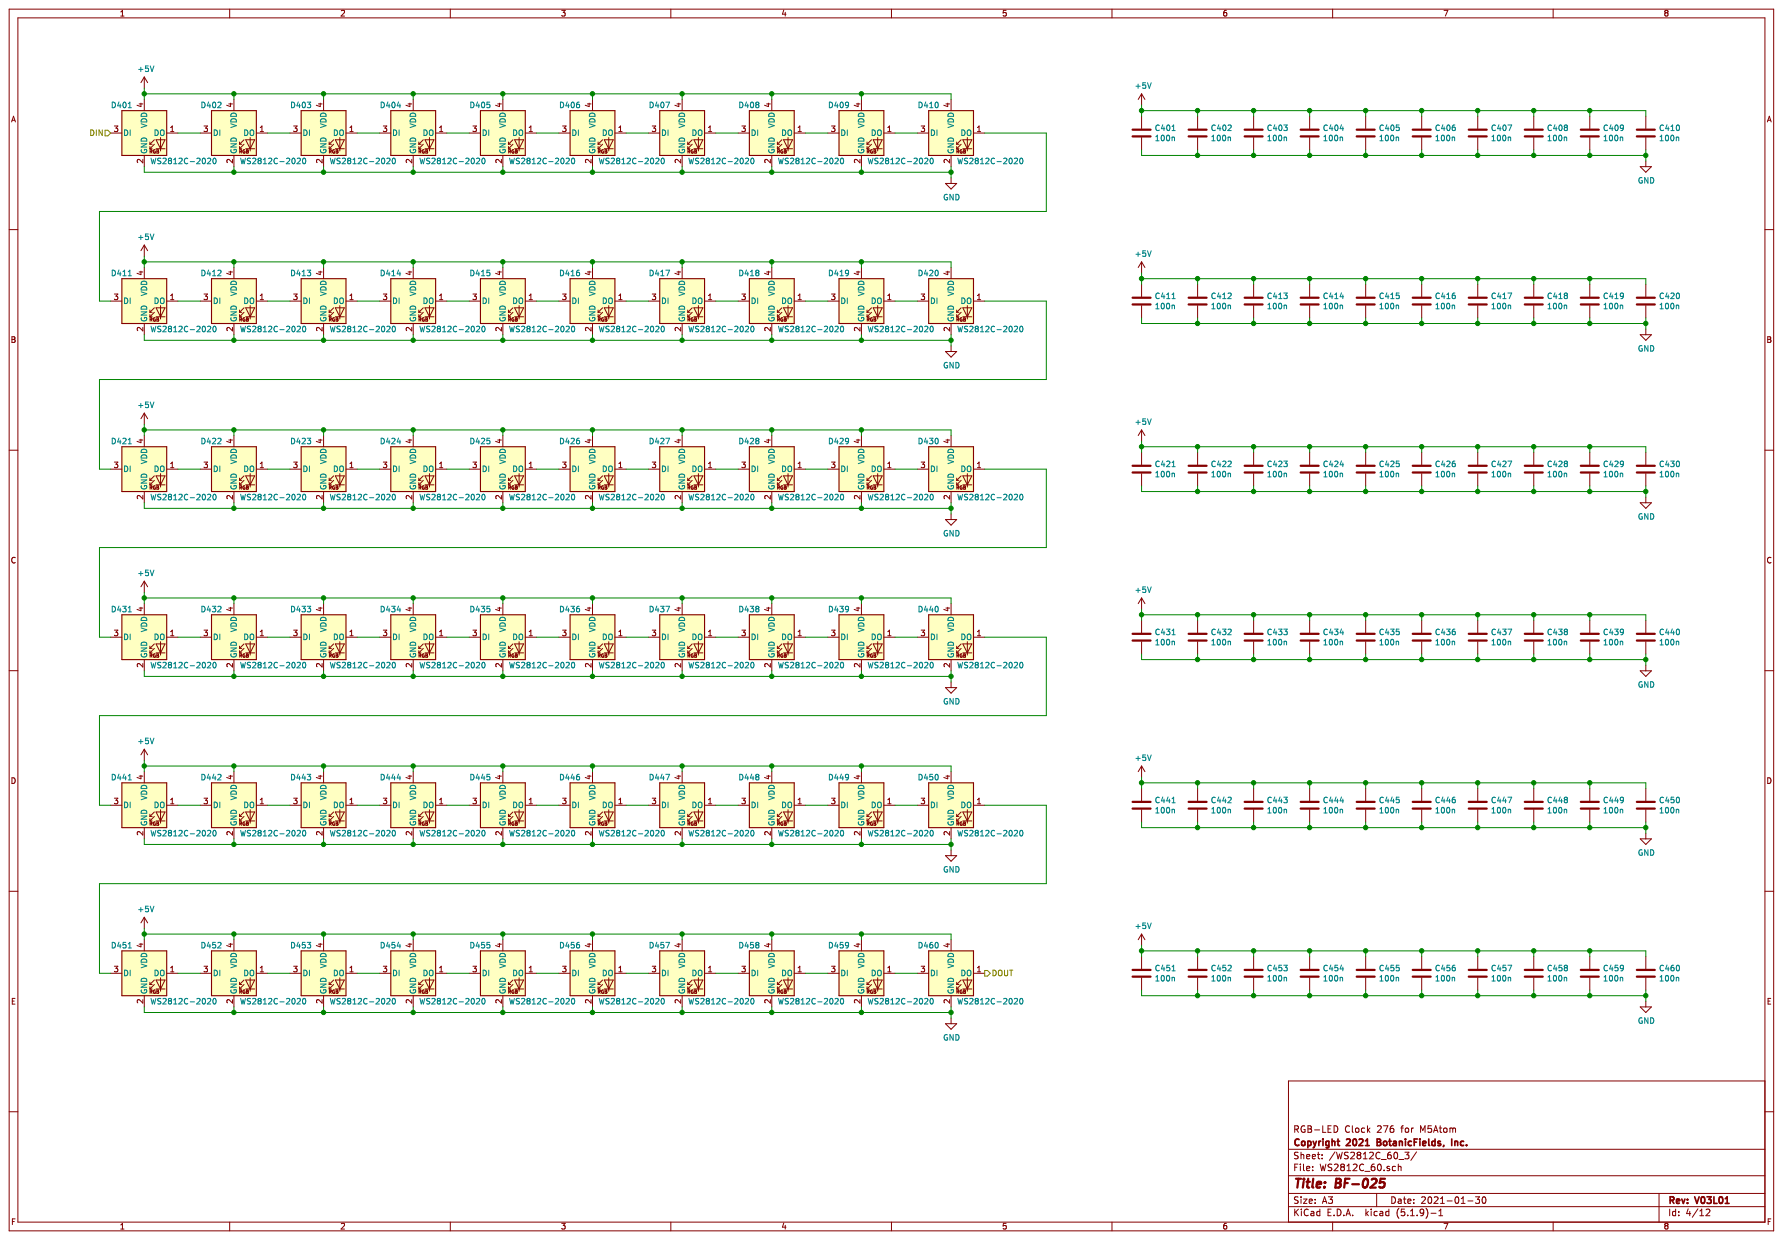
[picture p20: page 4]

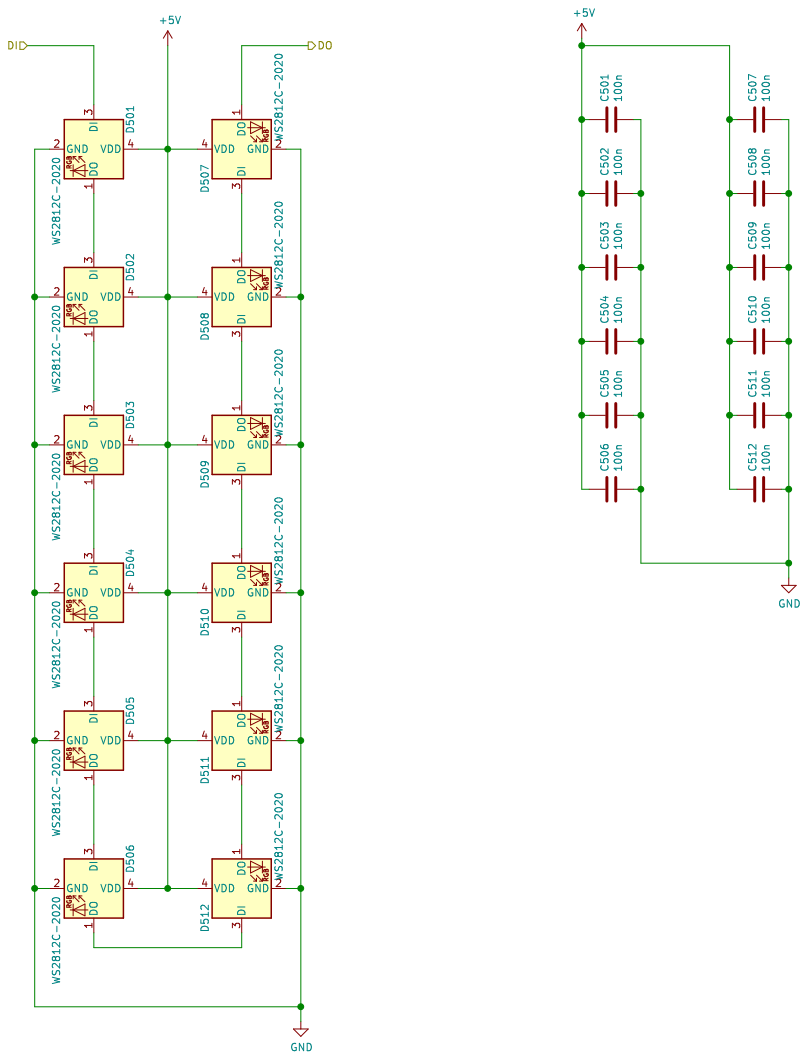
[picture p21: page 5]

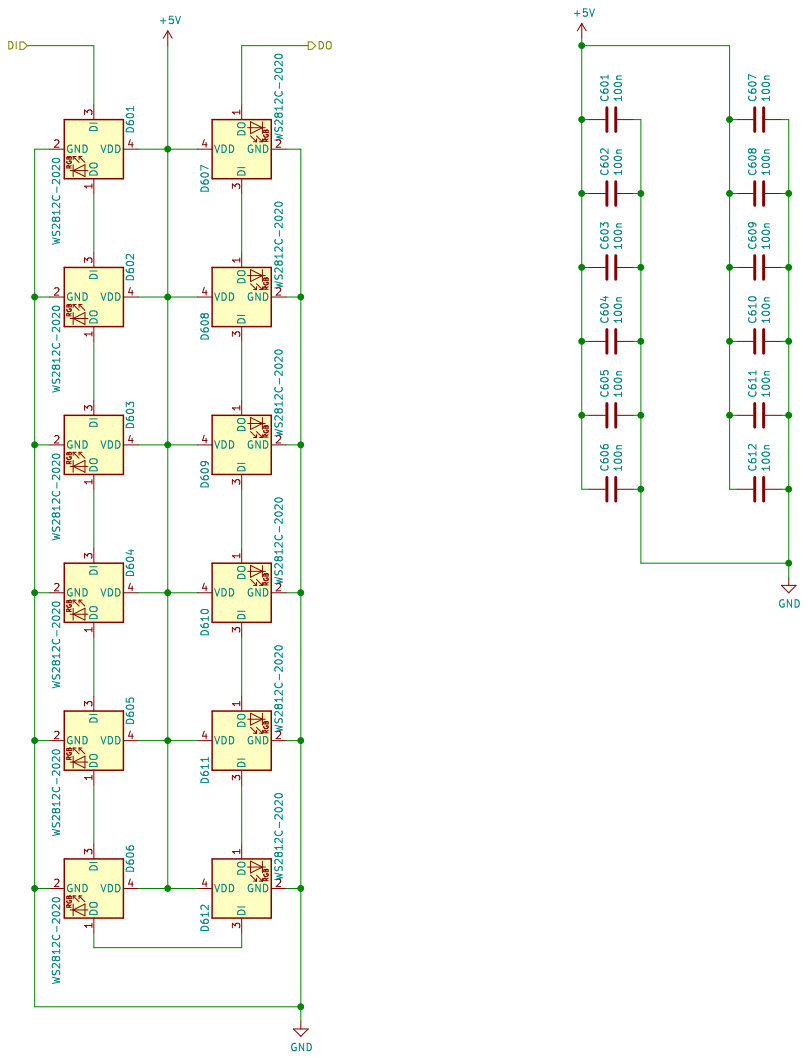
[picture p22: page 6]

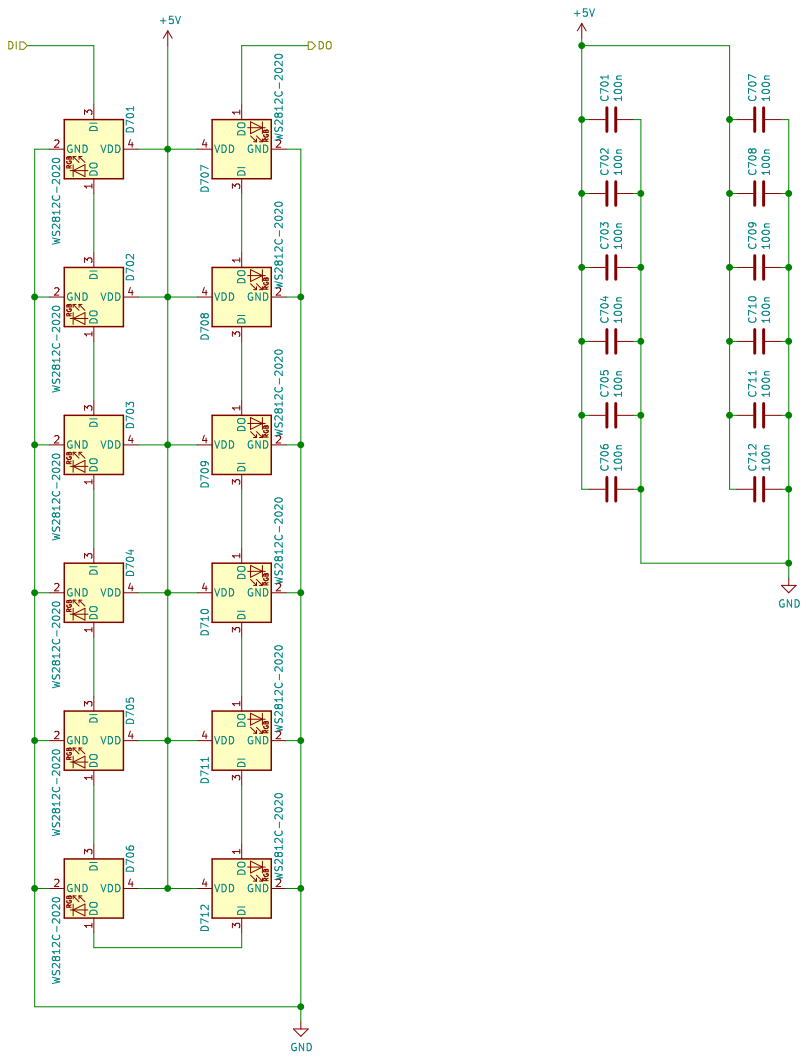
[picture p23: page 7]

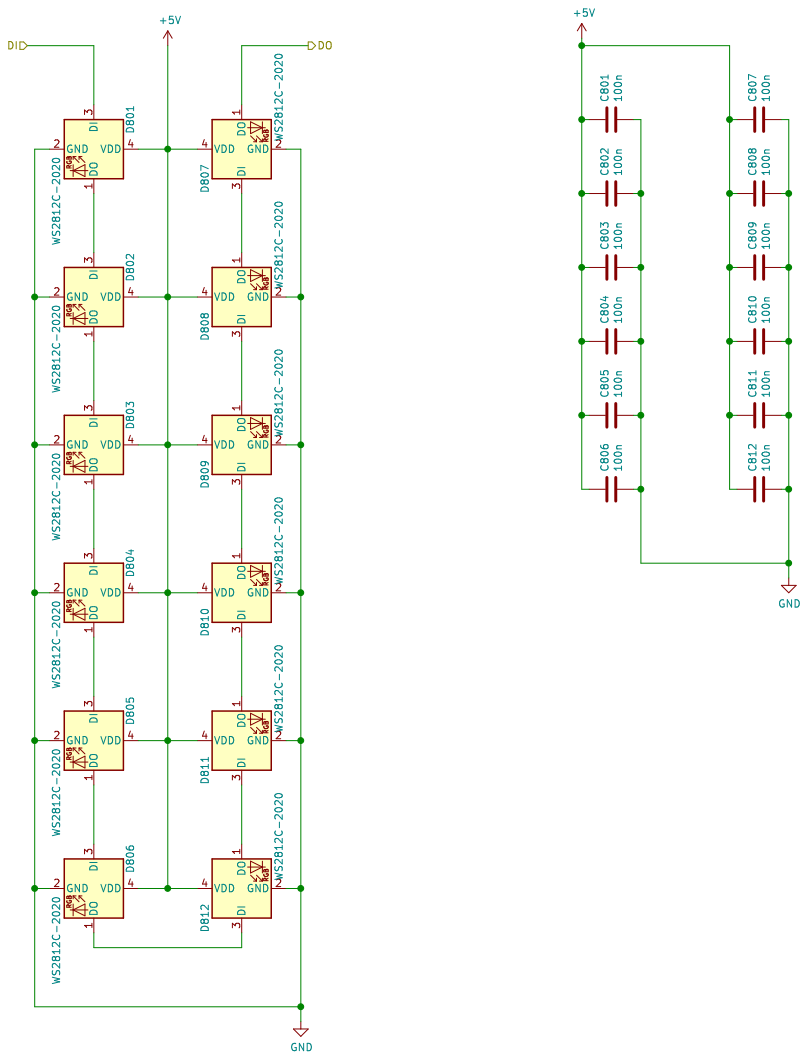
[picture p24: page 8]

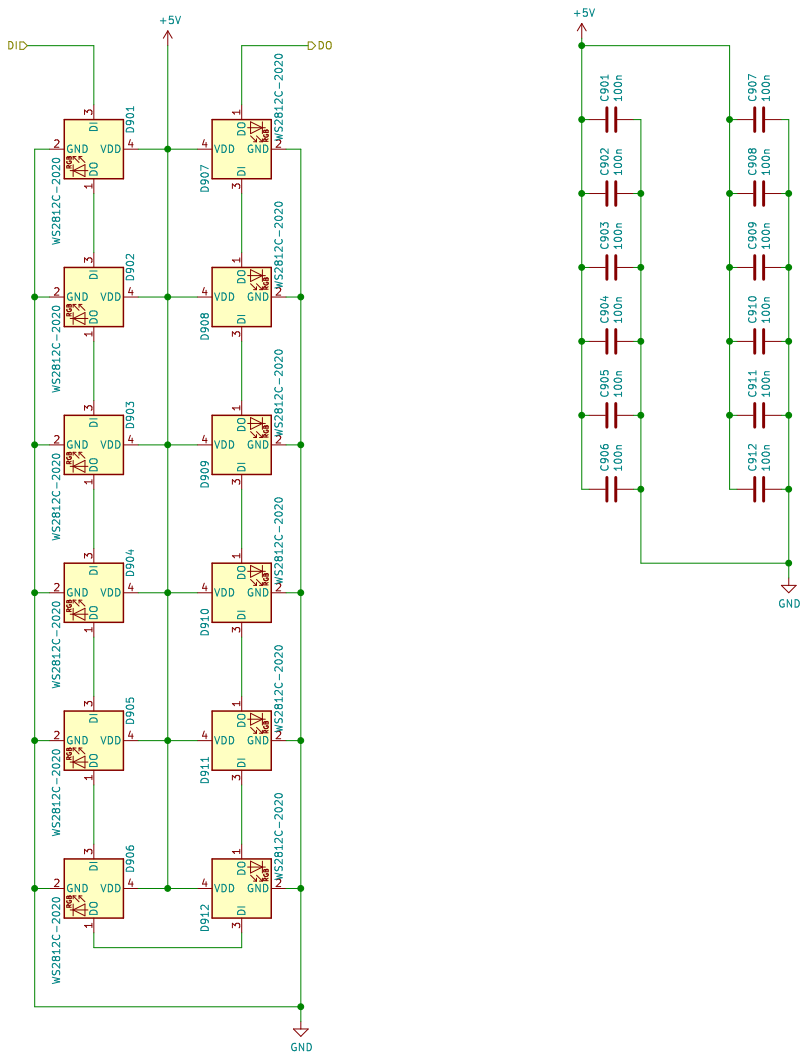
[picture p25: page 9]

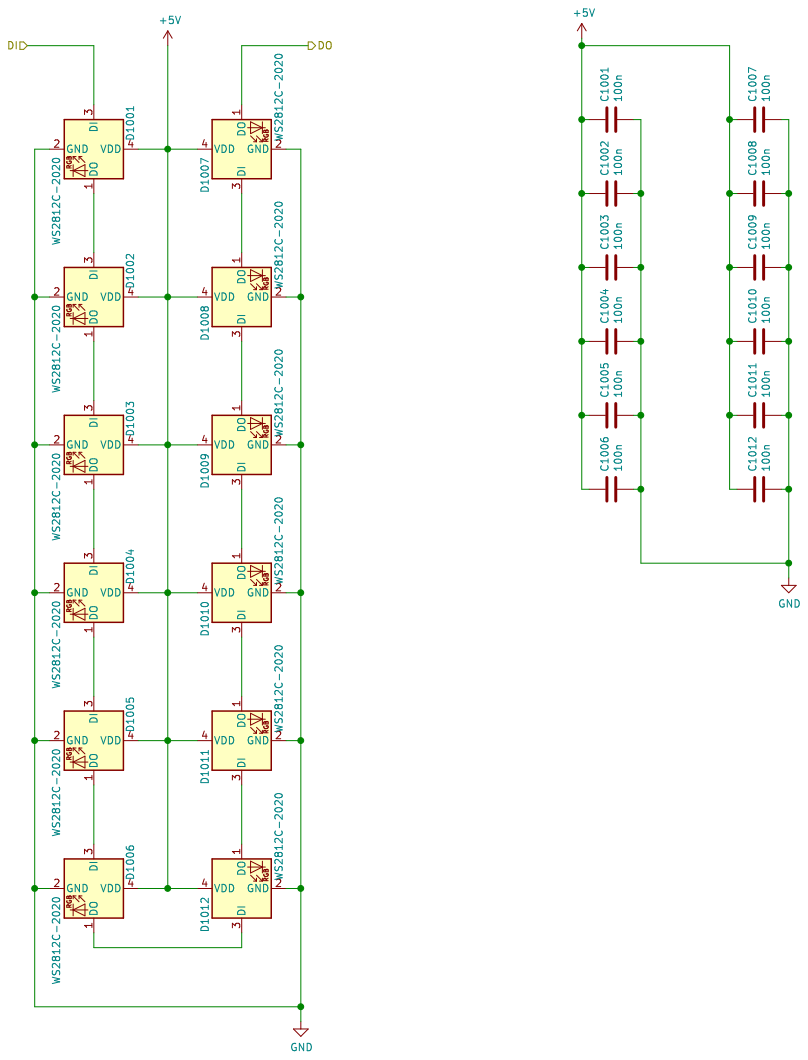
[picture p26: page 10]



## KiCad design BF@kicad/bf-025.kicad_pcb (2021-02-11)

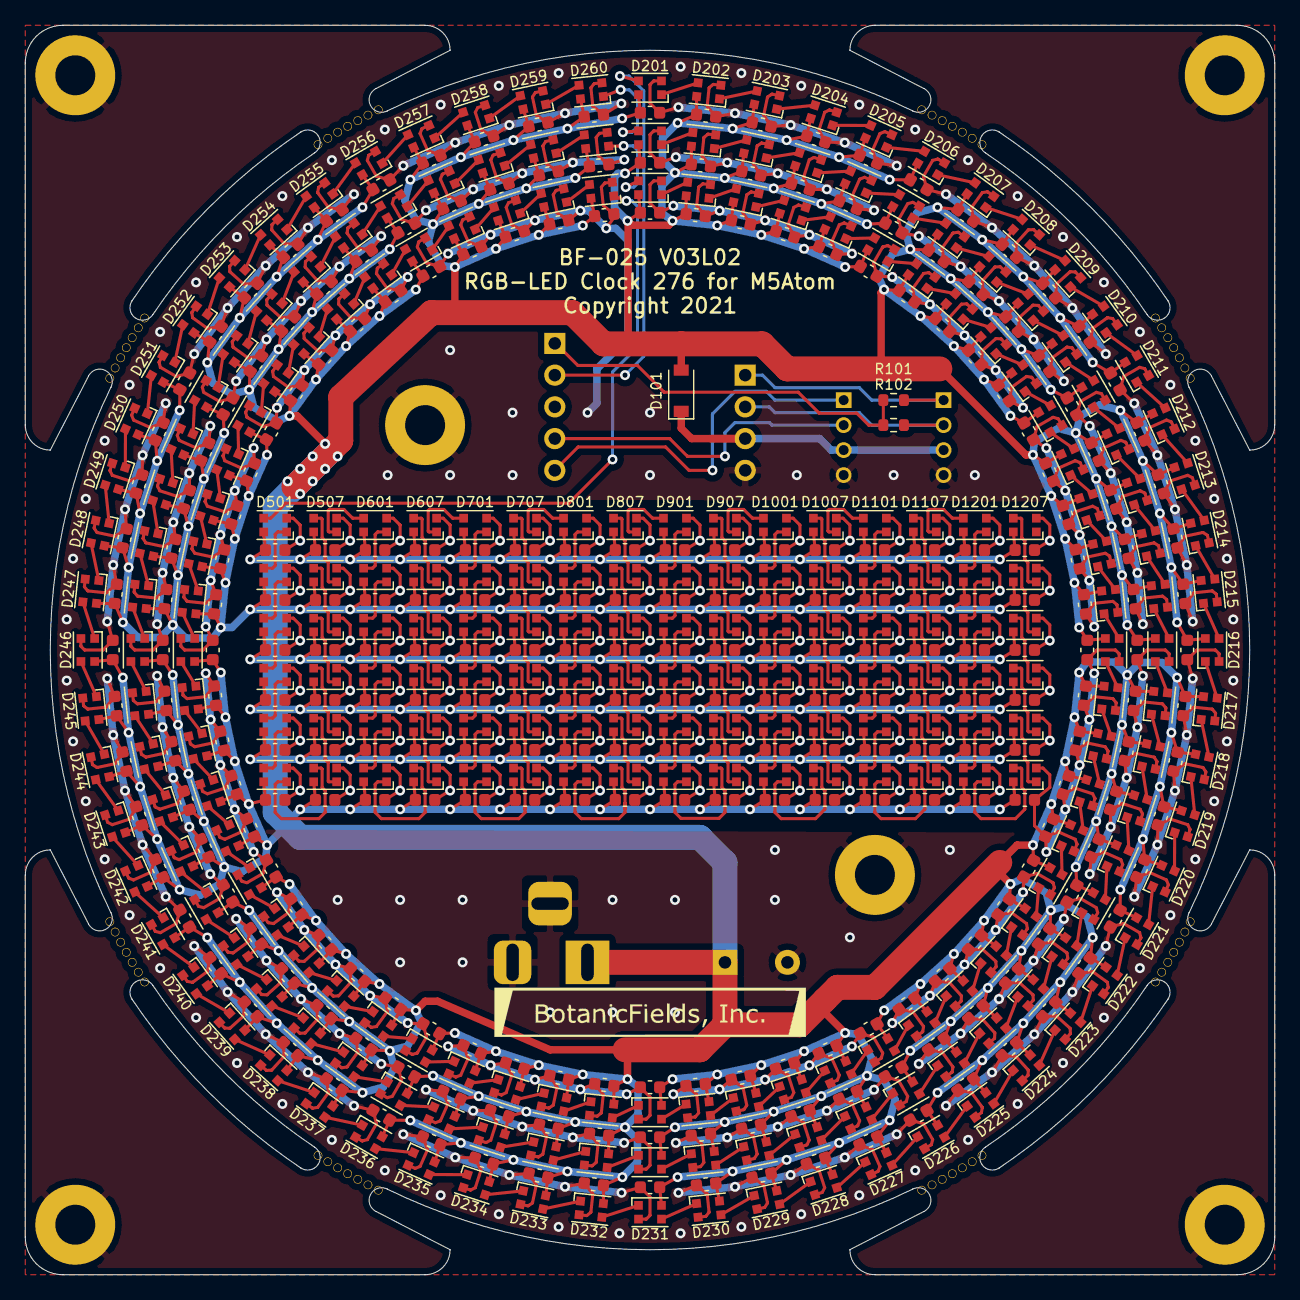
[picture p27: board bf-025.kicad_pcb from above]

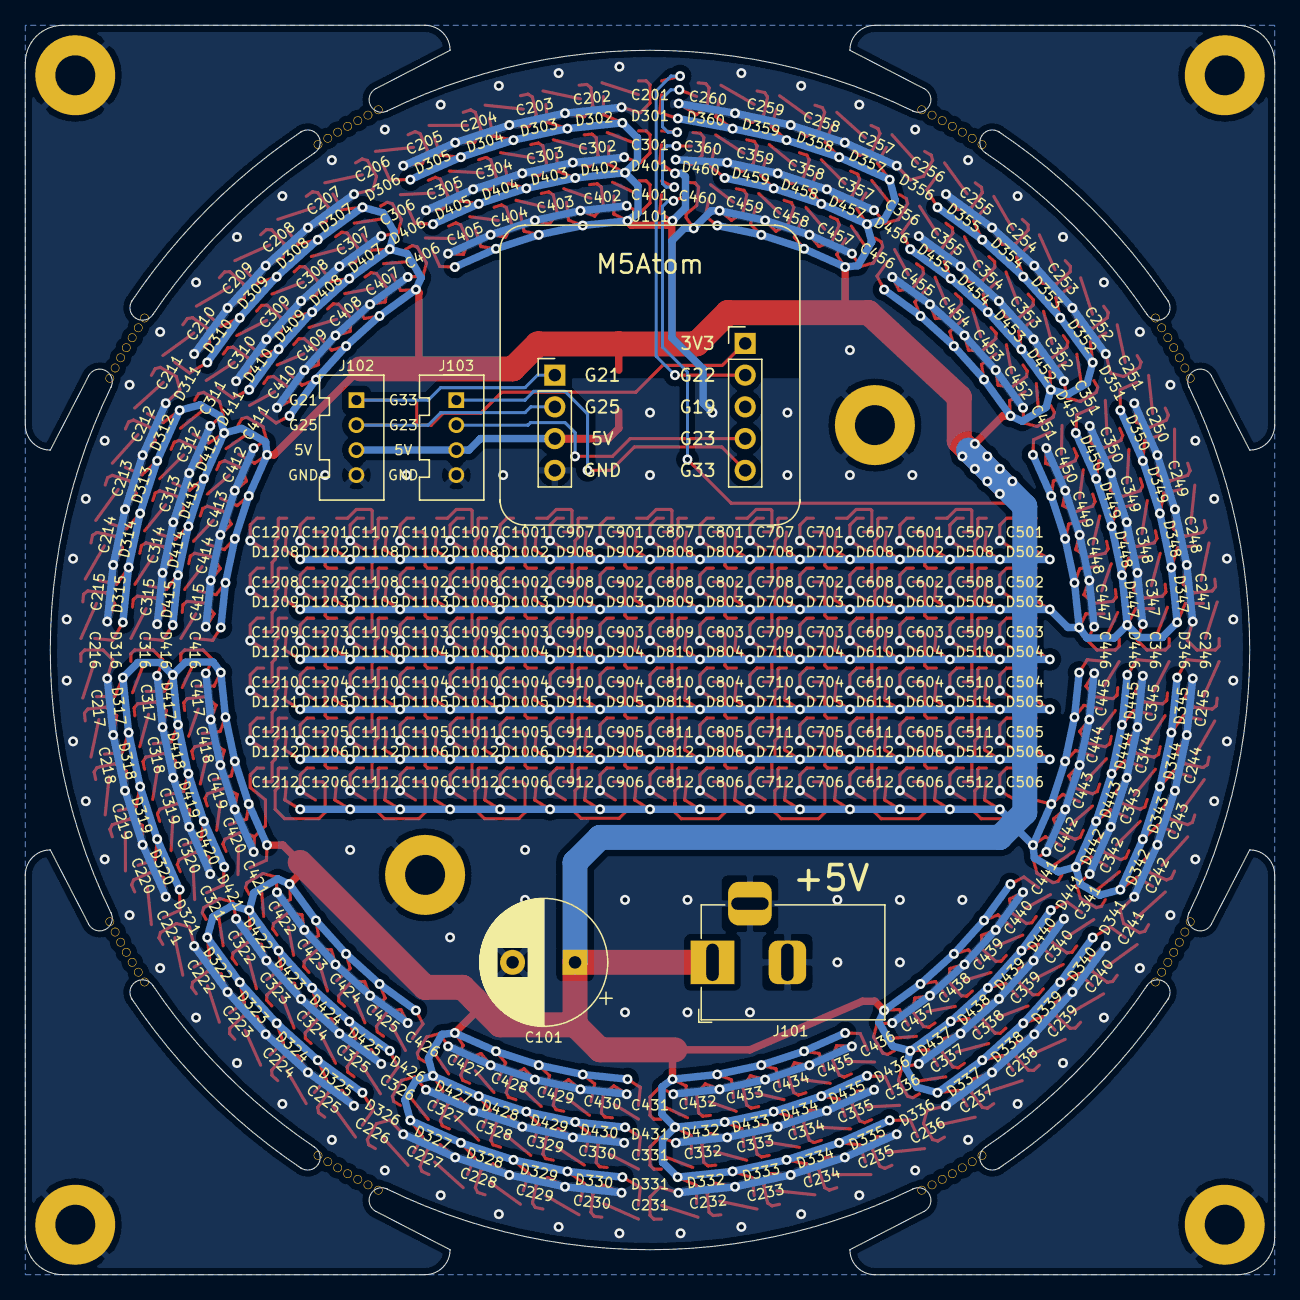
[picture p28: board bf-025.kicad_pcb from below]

Board: 2 copper layers, 100.0 x 100.0 mm, 560 parts (5 on the bottom side), 284 nets.

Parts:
C101: 1000u; CP_Radial_D10.0mm_P5.00mm
C201, C202, C203, C204, C205, C206, C207, C208, C209, C210, C211, C212, C213, C214, C215, C216, C217, C218, C219, C220, C221, C222, C223, C224, C225, C226, C227, C228, C229, C230, C231, C232, C233, C234, C235, C236, C237, C238, C239, C240, C241, C242, C243, C244, C245, C246, C247, C248, C249, C250, C251, C252, C253, C254, C255, C256, C257, C258, C259, C260, C301, C302, C303, C304, C305, C306, C307, C308, C309, C310, C311, C312, C313, C314, C315, C316, C317, C318, C319, C320, C321, C322, C323, C324, C325, C326, C327, C328, C329, C330, C331, C332, C333, C334, C335, C336, C337, C338, C339, C340, C341, C342, C343, C344, C345, C346, C347, C348, C349, C350, C351, C352, C353, C354, C355, C356, C357, C358, C359, C360, C401, C402, C403, C404, C405, C406, C407, C408, C409, C410, C411, C412, C413, C414, C415, C416, C417, C418, C419, C420, C421, C422, C423, C424, C425, C426, C427, C428, C429, C430, C431, C432, C433, C434, C435, C436, C437, C438, C439, C440, C441, C442, C443, C444, C445, C446, C447, C448, C449, C450, C451, C452, C453, C454, C455, C456, C457, C458, C459, C460, C501, C502, C503, C504, C505, C506, C507, C508, C509, C510, C511, C512, C601, C602, C603, C604, C605, C606, C607, C608, C609, C610, C611, C612, C701, C702, C703, C704, C705, C706, C707, C708, C709, C710, C711, C712, C801, C802, C803, C804, C805, C806, C807, C808, C809, C810, C811, C812, C901, C902, C903, C904, C905, C906, C907, C908, C909, C910, C911, C912, C1001, C1002, C1003, C1004, C1005, C1006, C1007, C1008, C1009, C1010, C1011, C1012, C1101, C1102, C1103, C1104, C1105, C1106, C1107, C1108, C1109, C1110, C1111, C1112, C1201, C1202, C1203, C1204, C1205, C1206, C1207, C1208, C1209, C1210, C1211, C1212: 100n; C_0603_1608Metric
D101: B5819W; D_SOD-123
D201, D202, D203, D204, D205, D206, D207, D208, D209, D210, D211, D212, D213, D214, D215, D216, D217, D218, D219, D220, D221, D222, D223, D224, D225, D226, D227, D228, D229, D230, D231, D232, D233, D234, D235, D236, D237, D238, D239, D240, D241, D242, D243, D244, D245, D246, D247, D248, D249, D250, D251, D252, D253, D254, D255, D256, D257, D258, D259, D260, D301, D302, D303, D304, D305, D306, D307, D308, D309, D310, D311, D312, D313, D314, D315, D316, D317, D318, D319, D320, D321, D322, D323, D324, D325, D326, D327, D328, D329, D330, D331, D332, D333, D334, D335, D336, D337, D338, D339, D340, D341, D342, D343, D344, D345, D346, D347, D348, D349, D350, D351, D352, D353, D354, D355, D356, D357, D358, D359, D360, D401, D402, D403, D404, D405, D406, D407, D408, D409, D410, D411, D412, D413, D414, D415, D416, D417, D418, D419, D420, D421, D422, D423, D424, D425, D426, D427, D428, D429, D430, D431, D432, D433, D434, D435, D436, D437, D438, D439, D440, D441, D442, D443, D444, D445, D446, D447, D448, D449, D450, D451, D452, D453, D454, D455, D456, D457, D458, D459, D460, D501, D502, D503, D504, D505, D506, D507, D508, D509, D510, D511, D512, D601, D602, D603, D604, D605, D606, D607, D608, D609, D610, D611, D612, D701, D702, D703, D704, D705, D706, D707, D708, D709, D710, D711, D712, D801, D802, D803, D804, D805, D806, D807, D808, D809, D810, D811, D812, D901, D902, D903, D904, D905, D906, D907, D908, D909, D910, D911, D912, D1001, D1002, D1003, D1004, D1005, D1006, D1007, D1008, D1009, D1010, D1011, D1012, D1101, D1102, D1103, D1104, D1105, D1106, D1107, D1108, D1109, D1110, D1111, D1112, D1201, D1202, D1203, D1204, D1205, D1206, D1207, D1208, D1209, D1210, D1211, D1212: WS2812C-2020; BF@WS2812C-2020
J101: Barrel_Jack_Switch; BF@BarrelJack_Horizontal
J102: I2C; HW4-2.0
J103: UART; HW4-2.0
R101, R102: 10k; R_0603_1608Metric
U101: M5Atom; BF@M5Atom

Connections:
+5V: C101.1, C201.1, C202.1, C203.1, C204.1, C205.1, C206.1, C207.1, C208.1, C209.1, C210.1, C211.1, C212.1, C213.1, C214.1, C215.1, C216.1, C217.1, C218.1, C219.1, C220.1, C221.1, C222.1, C223.1, C224.1, C225.1, C226.1, C227.1, C228.1, C229.1, C230.1, C231.1, C232.1, C233.1, C234.1, C235.1, C236.1, C237.1, C238.1, C239.1, C240.1, C241.1, C242.1, C243.1, C244.1, C245.1, C246.1, C247.1, C248.1, C249.1, C250.1, C251.1, C252.1, C253.1, C254.1, C255.1, C256.1, C257.1, C258.1, C259.1, C260.1, C301.1, C302.1, C303.1, C304.1, C305.1, C306.1, C307.1, C308.1, C309.1, C310.1, C311.1, C312.1, C313.1, C314.1, C315.1, C316.1, C317.1, C318.1, C319.1, C320.1, C321.1, C322.1, C323.1, C324.1, C325.1, C326.1, C327.1, C328.1, C329.1, C330.1, C331.1, C332.1, C333.1, C334.1, C335.1, C336.1, C337.1, C338.1, C339.1, C340.1, C341.1, C342.1, C343.1, C344.1, C345.1, C346.1, C347.1, C348.1, C349.1, C350.1, C351.1, C352.1, C353.1, C354.1, C355.1, C356.1, C357.1, C358.1, C359.1, C360.1, C401.1, C402.1, C403.1, C404.1, C405.1, C406.1, C407.1, C408.1, C409.1, C410.1, C411.1, C412.1, C413.1, C414.1, C415.1, C416.1, C417.1, C418.1, C419.1, C420.1, C421.1, C422.1, C423.1, C424.1, C425.1, C426.1, C427.1, C428.1, C429.1, C430.1, C431.1, C432.1, C433.1, C434.1, C435.1, C436.1, C437.1, C438.1, C439.1, C440.1, C441.1, C442.1, C443.1, C444.1, C445.1, C446.1, C447.1, C448.1, C449.1, C450.1, C451.1, C452.1, C453.1, C454.1, C455.1, C456.1, C457.1, C458.1, C459.1, C460.1, C501.1, C502.1, C503.1, C504.1, C505.1, C506.1, C507.1, C508.1, C509.1, C510.1, C511.1, C512.1, C601.1, C602.1, C603.1, C604.1, C605.1, C606.1, C607.1, C608.1, C609.1, C610.1, C611.1, C612.1, C701.1, C702.1, C703.1, C704.1, C705.1, C706.1, C707.1, C708.1, C709.1, C710.1, C711.1, C712.1, C801.1, C802.1, C803.1, C804.1, C805.1, C806.1, C807.1, C808.1, C809.1, C810.1, C811.1, C812.1, C901.1, C902.1, C903.1, C904.1, C905.1, C906.1, C907.1, C908.1, C909.1, C910.1, C911.1, C912.1, C1001.1, C1002.1, C1003.1, C1004.1, C1005.1, C1006.1, C1007.1, C1008.1, C1009.1, C1010.1, C1011.1, C1012.1, C1101.1, C1102.1, C1103.1, C1104.1, C1105.1, C1106.1, C1107.1, C1108.1, C1109.1, C1110.1, C1111.1, C1112.1, C1201.1, C1202.1, C1203.1, C1204.1, C1205.1, C1206.1, C1207.1, C1208.1, C1209.1, C1210.1, C1211.1, C1212.1, D101.2, D201.4, D202.4, D203.4, D204.4, D205.4, D206.4, D207.4, D208.4, D209.4, D210.4, D211.4, D212.4, D213.4, D214.4, D215.4, D216.4, D217.4, D218.4, D219.4, D220.4, D221.4, D222.4, D223.4, D224.4, D225.4, D226.4, D227.4, D228.4, D229.4, D230.4, D231.4, D232.4, D233.4, D234.4, D235.4, D236.4, D237.4, D238.4, D239.4, D240.4, D241.4, D242.4, D243.4, D244.4, D245.4, D246.4, D247.4, D248.4, D249.4, D250.4, D251.4, D252.4, D253.4, D254.4, D255.4, D256.4, D257.4, D258.4, D259.4, D260.4, D301.4, D302.4, D303.4, D304.4, D305.4, D306.4, D307.4, D308.4, D309.4, D310.4, D311.4, D312.4, D313.4, D314.4, D315.4, D316.4, D317.4, D318.4, D319.4, D320.4, D321.4, D322.4, D323.4, D324.4, D325.4, D326.4, D327.4, D328.4, D329.4, D330.4, D331.4, D332.4, D333.4, D334.4, D335.4, D336.4, D337.4, D338.4, D339.4, D340.4, D341.4, D342.4, D343.4, D344.4, D345.4, D346.4, D347.4, D348.4, D349.4, D350.4, D351.4, D352.4, D353.4, D354.4, D355.4, D356.4, D357.4, D358.4, D359.4, D360.4, D401.4, D402.4, D403.4, D404.4, D405.4, D406.4, D407.4, D408.4, D409.4, D410.4, D411.4, D412.4, D413.4, D414.4, D415.4, D416.4, D417.4, D418.4, D419.4, D420.4, D421.4, D422.4, D423.4, D424.4, D425.4, D426.4, D427.4, D428.4, D429.4, D430.4, D431.4, D432.4, D433.4, D434.4, D435.4, D436.4, D437.4, D438.4, D439.4, D440.4, D441.4, D442.4, D443.4, D444.4, D445.4, D446.4, D447.4, D448.4, D449.4, D450.4, D451.4, D452.4, D453.4, D454.4, D455.4, D456.4, D457.4, D458.4, D459.4, D460.4, D501.4, D502.4, D503.4, D504.4, D505.4, D506.4, D507.4, D508.4, D509.4, D510.4, D511.4, D512.4, D601.4, D602.4, D603.4, D604.4, D605.4, D606.4, D607.4, D608.4, D609.4, D610.4, D611.4, D612.4, D701.4, D702.4, D703.4, D704.4, D705.4, D706.4, D707.4, D708.4, D709.4, D710.4, D711.4, D712.4, D801.4, D802.4, D803.4, D804.4, D805.4, D806.4, D807.4, D808.4, D809.4, D810.4, D811.4, D812.4, D901.4, D902.4, D903.4, D904.4, D905.4, D906.4, D907.4, D908.4, D909.4, D910.4, D911.4, D912.4, D1001.4, D1002.4, D1003.4, D1004.4, D1005.4, D1006.4, D1007.4, D1008.4, D1009.4, D1010.4, D1011.4, D1012.4, D1101.4, D1102.4, D1103.4, D1104.4, D1105.4, D1106.4, D1107.4, D1108.4, D1109.4, D1110.4, D1111.4, D1112.4, D1201.4, D1202.4, D1203.4, D1204.4, D1205.4, D1206.4, D1207.4, D1208.4, D1209.4, D1210.4, D1211.4, D1212.4, J101.1
/G21: J102.1, R101.2, U101.1
/G23_G34: J103.2, U101.6
/G25: J102.2, R102.2, U101.2
/G33: J103.1, U101.5
/M5_3V3: R101.1, R102.1, U101.9
/M5_5V: D101.1, J102.3, J103.3, U101.3
/WS2812C_12_1/DI: D460.1, D501.3
/WS2812C_12_2/DI: D507.1, D601.3
/WS2812C_12_3/DI: D607.1, D701.3
/WS2812C_12_4/DI: D707.1, D801.3
/WS2812C_12_5/DI: D807.1, D901.3
/WS2812C_12_6/DI: D907.1, D1001.3
/WS2812C_12_7/DI: D1007.1, D1101.3
/WS2812C_12_8/DI: D1107.1, D1201.3
/WS2812C_60_1/DIN: D201.3, U101.8
/WS2812C_60_2/DIN: D260.1, D301.3
/WS2812C_60_3/DIN: D360.1, D401.3
GND: C101.2, C201.2, C202.2, C203.2, C204.2, C205.2, C206.2, C207.2, C208.2, C209.2, C210.2, C211.2, C212.2, C213.2, C214.2, C215.2, C216.2, C217.2, C218.2, C219.2, C220.2, C221.2, C222.2, C223.2, C224.2, C225.2, C226.2, C227.2, C228.2, C229.2, C230.2, C231.2, C232.2, C233.2, C234.2, C235.2, C236.2, C237.2, C238.2, C239.2, C240.2, C241.2, C242.2, C243.2, C244.2, C245.2, C246.2, C247.2, C248.2, C249.2, C250.2, C251.2, C252.2, C253.2, C254.2, C255.2, C256.2, C257.2, C258.2, C259.2, C260.2, C301.2, C302.2, C303.2, C304.2, C305.2, C306.2, C307.2, C308.2, C309.2, C310.2, C311.2, C312.2, C313.2, C314.2, C315.2, C316.2, C317.2, C318.2, C319.2, C320.2, C321.2, C322.2, C323.2, C324.2, C325.2, C326.2, C327.2, C328.2, C329.2, C330.2, C331.2, C332.2, C333.2, C334.2, C335.2, C336.2, C337.2, C338.2, C339.2, C340.2, C341.2, C342.2, C343.2, C344.2, C345.2, C346.2, C347.2, C348.2, C349.2, C350.2, C351.2, C352.2, C353.2, C354.2, C355.2, C356.2, C357.2, C358.2, C359.2, C360.2, C401.2, C402.2, C403.2, C404.2, C405.2, C406.2, C407.2, C408.2, C409.2, C410.2, C411.2, C412.2, C413.2, C414.2, C415.2, C416.2, C417.2, C418.2, C419.2, C420.2, C421.2, C422.2, C423.2, C424.2, C425.2, C426.2, C427.2, C428.2, C429.2, C430.2, C431.2, C432.2, C433.2, C434.2, C435.2, C436.2, C437.2, C438.2, C439.2, C440.2, C441.2, C442.2, C443.2, C444.2, C445.2, C446.2, C447.2, C448.2, C449.2, C450.2, C451.2, C452.2, C453.2, C454.2, C455.2, C456.2, C457.2, C458.2, C459.2, C460.2, C501.2, C502.2, C503.2, C504.2, C505.2, C506.2, C507.2, C508.2, C509.2, C510.2, C511.2, C512.2, C601.2, C602.2, C603.2, C604.2, C605.2, C606.2, C607.2, C608.2, C609.2, C610.2, C611.2, C612.2, C701.2, C702.2, C703.2, C704.2, C705.2, C706.2, C707.2, C708.2, C709.2, C710.2, C711.2, C712.2, C801.2, C802.2, C803.2, C804.2, C805.2, C806.2, C807.2, C808.2, C809.2, C810.2, C811.2, C812.2, C901.2, C902.2, C903.2, C904.2, C905.2, C906.2, C907.2, C908.2, C909.2, C910.2, C911.2, C912.2, C1001.2, C1002.2, C1003.2, C1004.2, C1005.2, C1006.2, C1007.2, C1008.2, C1009.2, C1010.2, C1011.2, C1012.2, C1101.2, C1102.2, C1103.2, C1104.2, C1105.2, C1106.2, C1107.2, C1108.2, C1109.2, C1110.2, C1111.2, C1112.2, C1201.2, C1202.2, C1203.2, C1204.2, C1205.2, C1206.2, C1207.2, C1208.2, C1209.2, C1210.2, C1211.2, C1212.2, D201.2, D202.2, D203.2, D204.2, D205.2, D206.2, D207.2, D208.2, D209.2, D210.2, D211.2, D212.2, D213.2, D214.2, D215.2, D216.2, D217.2, D218.2, D219.2, D220.2, D221.2, D222.2, D223.2, D224.2, D225.2, D226.2, D227.2, D228.2, D229.2, D230.2, D231.2, D232.2, D233.2, D234.2, D235.2, D236.2, D237.2, D238.2, D239.2, D240.2, D241.2, D242.2, D243.2, D244.2, D245.2, D246.2, D247.2, D248.2, D249.2, D250.2, D251.2, D252.2, D253.2, D254.2, D255.2, D256.2, D257.2, D258.2, D259.2, D260.2, D301.2, D302.2, D303.2, D304.2, D305.2, D306.2, D307.2, D308.2, D309.2, D310.2, D311.2, D312.2, D313.2, D314.2, D315.2, D316.2, D317.2, D318.2, D319.2, D320.2, D321.2, D322.2, D323.2, D324.2, D325.2, D326.2, D327.2, D328.2, D329.2, D330.2, D331.2, D332.2, D333.2, D334.2, D335.2, D336.2, D337.2, D338.2, D339.2, D340.2, D341.2, D342.2, D343.2, D344.2, D345.2, D346.2, D347.2, D348.2, D349.2, D350.2, D351.2, D352.2, D353.2, D354.2, D355.2, D356.2, D357.2, D358.2, D359.2, D360.2, D401.2, D402.2, D403.2, D404.2, D405.2, D406.2, D407.2, D408.2, D409.2, D410.2, D411.2, D412.2, D413.2, D414.2, D415.2, D416.2, D417.2, D418.2, D419.2, D420.2, D421.2, D422.2, D423.2, D424.2, D425.2, D426.2, D427.2, D428.2, D429.2, D430.2, D431.2, D432.2, D433.2, D434.2, D435.2, D436.2, D437.2, D438.2, D439.2, D440.2, D441.2, D442.2, D443.2, D444.2, D445.2, D446.2, D447.2, D448.2, D449.2, D450.2, D451.2, D452.2, D453.2, D454.2, D455.2, D456.2, D457.2, D458.2, D459.2, D460.2, D501.2, D502.2, D503.2, D504.2, D505.2, D506.2, D507.2, D508.2, D509.2, D510.2, D511.2, D512.2, D601.2, D602.2, D603.2, D604.2, D605.2, D606.2, D607.2, D608.2, D609.2, D610.2, D611.2, D612.2, D701.2, D702.2, D703.2, D704.2, D705.2, D706.2, D707.2, D708.2, D709.2, D710.2, D711.2, D712.2, D801.2, D802.2, D803.2, D804.2, D805.2, D806.2, D807.2, D808.2, D809.2, D810.2, D811.2, D812.2, D901.2, D902.2, D903.2, D904.2, D905.2, D906.2, D907.2, D908.2, D909.2, D910.2, D911.2, D912.2, D1001.2, D1002.2, D1003.2, D1004.2, D1005.2, D1006.2, D1007.2, D1008.2, D1009.2, D1010.2, D1011.2, D1012.2, D1101.2, D1102.2, D1103.2, D1104.2, D1105.2, D1106.2, D1107.2, D1108.2, D1109.2, D1110.2, D1111.2, D1112.2, D1201.2, D1202.2, D1203.2, D1204.2, D1205.2, D1206.2, D1207.2, D1208.2, D1209.2, D1210.2, D1211.2, D1212.2, J101.2, J101.3, J102.4, J103.4, U101.4
unnamed: D201.1, D202.3
unnamed: D202.1, D203.3
unnamed: D203.1, D204.3
unnamed: D204.1, D205.3
unnamed: D205.1, D206.3
unnamed: D206.1, D207.3
unnamed: D207.1, D208.3
unnamed: D208.1, D209.3
unnamed: D209.1, D210.3
unnamed: D210.1, D211.3
unnamed: D211.1, D212.3
unnamed: D212.1, D213.3
unnamed: D213.1, D214.3
unnamed: D214.1, D215.3
unnamed: D215.1, D216.3
unnamed: D216.1, D217.3
unnamed: D217.1, D218.3
unnamed: D218.1, D219.3
unnamed: D219.1, D220.3
unnamed: D220.1, D221.3
unnamed: D221.1, D222.3
unnamed: D222.1, D223.3
unnamed: D223.1, D224.3
unnamed: D224.1, D225.3
unnamed: D225.1, D226.3
unnamed: D226.1, D227.3
unnamed: D227.1, D228.3
unnamed: D228.1, D229.3
unnamed: D229.1, D230.3
unnamed: D230.1, D231.3
unnamed: D231.1, D232.3
unnamed: D232.1, D233.3
unnamed: D233.1, D234.3
unnamed: D234.1, D235.3
unnamed: D235.1, D236.3
unnamed: D236.1, D237.3
unnamed: D237.1, D238.3
unnamed: D238.1, D239.3
unnamed: D239.1, D240.3
unnamed: D240.1, D241.3
unnamed: D241.1, D242.3
unnamed: D242.1, D243.3
unnamed: D243.1, D244.3
unnamed: D244.1, D245.3
unnamed: D245.1, D246.3
unnamed: D246.1, D247.3
unnamed: D247.1, D248.3
unnamed: D248.1, D249.3
unnamed: D249.1, D250.3
unnamed: D250.1, D251.3
unnamed: D251.1, D252.3
unnamed: D252.1, D253.3
unnamed: D253.1, D254.3
unnamed: D254.1, D255.3
unnamed: D255.1, D256.3
unnamed: D256.1, D257.3
unnamed: D257.1, D258.3
unnamed: D258.1, D259.3
unnamed: D259.1, D260.3
unnamed: D301.1, D302.3
unnamed: D302.1, D303.3
unnamed: D303.1, D304.3
unnamed: D304.1, D305.3
unnamed: D305.1, D306.3
unnamed: D306.1, D307.3
unnamed: D307.1, D308.3
unnamed: D308.1, D309.3
unnamed: D309.1, D310.3
unnamed: D310.1, D311.3
unnamed: D311.1, D312.3
unnamed: D312.1, D313.3
unnamed: D313.1, D314.3
unnamed: D314.1, D315.3
unnamed: D315.1, D316.3
unnamed: D316.1, D317.3
unnamed: D317.1, D318.3
unnamed: D318.1, D319.3
unnamed: D319.1, D320.3
unnamed: D320.1, D321.3
unnamed: D321.1, D322.3
unnamed: D322.1, D323.3
unnamed: D323.1, D324.3
unnamed: D324.1, D325.3
unnamed: D325.1, D326.3
unnamed: D326.1, D327.3
unnamed: D327.1, D328.3
unnamed: D328.1, D329.3
unnamed: D329.1, D330.3
unnamed: D330.1, D331.3
unnamed: D331.1, D332.3
unnamed: D332.1, D333.3
unnamed: D333.1, D334.3
unnamed: D334.1, D335.3
unnamed: D335.1, D336.3
unnamed: D336.1, D337.3
unnamed: D337.1, D338.3
unnamed: D338.1, D339.3
unnamed: D339.1, D340.3
unnamed: D340.1, D341.3
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

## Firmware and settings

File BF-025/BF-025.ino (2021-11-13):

// Copyright 2021 BotanicFields, Inc.
// BF-025 RGB LED Clock 276 for M5Atom
// Demonstrations

#define FASTLED_ESP32_I2S true
//#define FASTLED_ALLOW_INTERRUPTS 0

#include <M5Atom.h>
#include "BF_Wifi.h"
#include "BF_Pcf8563.h"
#include "BF_RtcxNtp.h"
#include "BF_RGB_LED_276.h"
#include "BF_DemoClock.h"
#include "BF_DemoTimeShock.h"
#include "BF_DemoCylon.h"
#include "BF_DemoHueRing.h"
#include "BF_DemoNoise.h"

void setup()
{
  // button, Serial monitor, I2C
  const bool serial_enable(true);
  const bool i2c_enable(true);  // SDA = GPIO25, SCL = GPIO21, Frequency = 100kHz
  const bool display_enable(true);
  M5.begin(serial_enable, i2c_enable, !display_enable);

  // FastLED, Lamp test
  InitFastLed();
  LampTest();

  // RTC
  ShowPattern(pattern_rtc, 100);  // delay = 100ms
  rtcx.Begin(Wire);
  SetTimeFromRtcx();

  // Wi-Fi
  ShowPattern(pattern_wifi, 100);  // delay = 100ms
  WifiBegin();

  // NTP
  ShowPattern(pattern_ntp, 100);  // delay = 100ms
  NtpBegin();
}

void loop()
{
  ResetParameters();
  DemoClock();
  ResetParameters();
  DemoTimeShock();
  ResetParameters();
  DemoCylon();
  ResetParameters();
  DemoHueRing();
  ResetParameters();
  DemoNoise();
}

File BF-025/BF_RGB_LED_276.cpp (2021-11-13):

// Copyright 2021 BotanicFields, Inc.
// BF-025 RGB LED Clock 276 for M5Atom
// driver using FastLED

#define FASTLED_ESP32_I2S true
//#define FASTLED_ALLOW_INTERRUPTS 0

#include <M5Atom.h>
#include "BF_RGB_LED_276.h"

// parameters of FastLED
const int brightness_bf025  = 64;        // original for BF-025(WS2812C-2020)
const CRGB correction_bf025 = 0xB080FF;  // original for BF-025(WS2812C-2020)

// demonstration control
CRGB foreground_color       = CRGB::SlateGray;
CRGB background_color       = CRGB::Black;
CRGBPalette16 palette_color = RainbowColors_p;
int scale_factor            = 1;
int period_factor           = 1;

// control by the button
const int correction_select_default  = 0;
const int temperature_select_default = 0;
const int palette_select_default     = 0;
const int scale_select_default       = 3;
const int period_select_default      = 3;
int correction_select  = correction_select_default;
int temperature_select = temperature_select_default;
int palette_select     = palette_select_default;
int scale_select       = scale_select_default;
int period_select      = period_select_default;

// set color correction
//   omitted:
//     TypicalLEDStrip    = TypicalSMD5050
//     TypicalPixelString = Typical8mmPixel
void SelectCorrection(int &correction_select)
{
  switch (correction_select) {
  case  1: FastLED.setCorrection(TypicalSMD5050);    Serial.println("[RGB276]Correction: (1)TypicalSMD5050");    break;
  case  2: FastLED.setCorrection(Typical8mmPixel);   Serial.println("[RGB276]Correction: (2)Typical8mmPixel");   break;
  case  3: FastLED.setCorrection(UncorrectedColor);  Serial.println("[RGB276]Correction: (3)UncorrectedColor");  break;
  default: FastLED.setCorrection(correction_bf025);  Serial.println("[RGB276]Correction: (0)correction_bf025");
    correction_select = 0;
    break;
  }
}

// set color temperature
void SelectTemperature(int &temperature_select)
{
  switch (temperature_select) {
  case  1: FastLED.setTemperature(Candle);                   Serial.println("[RGB276]Temperature: ( 1)Candle");                   break;
  case  2: FastLED.setTemperature(Tungsten40W);              Serial.println("[RGB276]Temperature: ( 2)Tungsten40W");              break;
  case  3: FastLED.setTemperature(Tungsten100W);             Serial.println("[RGB276]Temperature: ( 3)Tungsten100W");             break;
  case  4: FastLED.setTemperature(Halogen);                  Serial.println("[RGB276]Temperature: ( 4)Halogen");                  break;
  case  5: FastLED.setTemperature(CarbonArc);                Serial.println("[RGB276]Temperature: ( 5)CarbonArc");                break;
  case  6: FastLED.setTemperature(HighNoonSun);              Serial.println("[RGB276]Temperature: ( 6)HighNoonSun");              break;
  case  7: FastLED.setTemperature(DirectSunlight);           Serial.println("[RGB276]Temperature: ( 7)DirectSunlight");           break;
  case  8: FastLED.setTemperature(OvercastSky);              Serial.println("[RGB276]Temperature: ( 8)OvercastSky");              break;
  case  9: FastLED.setTemperature(ClearBlueSky);             Serial.println("[RGB276]Temperature: ( 9)ClearBlueSky");             break;
  case 10: FastLED.setTemperature(WarmFluorescent);          Serial.println("[RGB276]Temperature: (10)WarmFluorescent");          break;
  case 11: FastLED.setTemperature(StandardFluorescent);      Serial.println("[RGB276]Temperature: (11)StandardFluorescent");      break;
  case 12: FastLED.setTemperature(CoolWhiteFluorescent);     Serial.println("[RGB276]Temperature: (12)CoolWhiteFluorescent");     break;
  case 13: FastLED.setTemperature(FullSpectrumFluorescent);  Serial.println("[RGB276]Temperature: (13)FullSpectrumFluorescent");  break;
  case 14: FastLED.setTemperature(GrowLightFluorescent);     Serial.println("[RGB276]Temperature: (14)GrowLightFluorescent");     break;
  case 15: FastLED.setTemperature(BlackLightFluorescent);    Serial.println("[RGB276]Temperature: (15)BlackLightFluorescent");    break;
  case 16: FastLED.setTemperature(MercuryVapor);             Serial.println("[RGB276]Temperature: (16)MercuryVapor");             break;
  case 17: FastLED.setTemperature(SodiumVapor);              Serial.println("[RGB276]Temperature: (17)SodiumVapor");              break;
  case 18: FastLED.setTemperature(MetalHalide);              Serial.println("[RGB276]Temperature: (18)MetalHalide");              break;
  case 19: FastLED.setTemperature(HighPressureSodium);       Serial.println("[RGB276]Temperature: (19)HighPressureSodium");       break;
  default: FastLED.setTemperature(UncorrectedTemperature);   Serial.println("[RGB276]Temperature: ( 0)UncorrectedTemperature");
    temperature_select = 0;
    break;
  }
}

// set color palette
//   omitted:
//     RainbowStripesColors_p = RainbowStripeColors_p
void SelectPalette(int &palette_select)
{
  switch (palette_select) {
  case  1: palette_color = CloudColors_p;          Serial.println("[RGB276]palette: (1)CloudColors_p");          break;
  case  2: palette_color = LavaColors_p;           Serial.println("[RGB276]palette: (2)LavaColors_p");           break;
  case  3: palette_color = OceanColors_p;          Serial.println("[RGB276]palette: (3)OceanColors_p");          break;
  case  4: palette_color = ForestColors_p;         Serial.println("[RGB276]palette: (4)ForestColors_p");         break;
  case  5: palette_color = RainbowStripeColors_p;  Serial.println("[RGB276]palette: (5)RainbowStripeColors_p");  break;
  case  6: palette_color = PartyColors_p;          Serial.println("[RGB276]palette: (6)PartyColors_p");          break;
  case  7: palette_color = HeatColors_p;           Serial.println("[RGB276]palette: (7)HeatColors_p");           break;
  default: palette_color = RainbowColors_p;        Serial.println("[RGB276]palette: (0)RainbowColors_p");
    palette_select = 0;
    break;
  }
}

// set scale factor for noise
void SelectScale(int &scale_select)
{
  switch (scale_select) {
  case  1: scale_factor = -5;  break;
  case  2: scale_factor = -2;  break;
  case  3: scale_factor =  1;  break;
  case  4: scale_factor =  2;  break;
  default: scale_factor =  5;
    scale_select = 0;
    break;
  }
  Serial.printf("[RGB276]scale: (%d) %d\n", scale_select, scale_factor);
}

// set period factor for noise
void SelectPeriod(int &period_select)
{
  switch (period_select) {
  case  1: period_factor = -10;  break;
  case  2: period_factor =  -2;  break;
  case  3: period_factor =   1;  break;
  case  4: period_factor =   2;  break;
  default: period_factor =  10;
    period_select = 0;
    break;
  }
  Serial.printf("[RGB276]period: (%d) %d\n", period_select, period_factor);
}
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

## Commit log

2021-01-10 KiCad Data
    Symbols, FootPrints, 3D
    [M5 ATOM Matrix.step, WS2812-2020.STEP]
2021-01-30 PCB data
    Add PCB data of V03L01
    [WS2812C_12.sch, WS2812C_60.sch, bf-025.kicad_pcb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]
2021-01-30 schema
    remove GND of unnecessary
2021-01-30 PCB data
    add PCB data
    [bf-025_bom.xlsx]
2021-01-31 PCB data
    footprint, 3d-omage
    [Grove Connector (standing).STEP, WS2812C_12.sch, bf-025.kicad_pcb]
2021-02-08 Create bf-025_led_connection.png
    description of LED connection
2021-02-11 V03L02
    update PCB layout
    [bf-025_bom.csv, bf-025_bom.xlsx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]
2021-02-11 V03L02
    update PCB
    [bf-025.kicad_pcb]
2021-02-12 gerber V03L02
    update PCB, eamples on YouTube
    [bf-025_bom.xlsx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]
2021-02-12 gerber V03L02
    change filename
2021-02-18 demo codes
    update demo codes
    [bf-25_demo.xlsx]
2021-02-21 Demo-Clock
    update code
    [bf-25_demo.xlsx]
2021-03-07 demo clock
    add "Time Shock"
    [bf-25_demo.xlsx]
2021-03-07 DemoTimeShock
    update button operation
    [bf-25_demo.xlsx]
2021-04-26 gerber V03L02
    [bf-025_bom.csv, bf-025_bom.xlsx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]
2021-05-05 Update bf-025_doc.pdf
    add round shaped board
2021-08-31 Noise, TimeShock
    add stand alone examples
    [BF_DemoNoise.cpp, BF_DemoTimeShock.cpp, BF_Noise.ino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]
2021-11-13 M5 Board Manager 2.0.0
    I2C process to update RTCx by SNTP callback, etc.
